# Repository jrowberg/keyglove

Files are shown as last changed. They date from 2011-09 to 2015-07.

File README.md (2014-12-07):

What is Keyglove?
=================

The [Keyglove](http://keyglove.net) is an [Arduino](http://arduino.cc)-powered glove that uses touch combinations to generate keyboard and mouse control codes. Once learned, the glove can easily be used without looking, making it perfect for embedded/wearable environments. The glove is thin and light, built to allow other activities (such as writing) without being in the way.

Keyglove Design
===============

Keyglove Prototype E

Because the glove design allows for multi-sensor combinations, the keyglove provides exponentially more possibilities than many other glove-based input devices (prototypes or commercial products). 34 strategically placed contact sensors and smart controller software make it possible to implement the entire English alphabet using simple one-to-one sensor contacts. When you include multi-sensor contacts, there are many hundreds of ergonomically usable combinations.

Development Status
==================

The Keyglove is still in the prototype stage with no fully working unit. For up-to-date development news, check out the [News](http://keyglove.net/news) page ([RSS here](http://keyglove.net/feed)) or follow the project on Twitter at [@keyglove](https://twitter.com/keyglove) or Facebook at https://fb.com/keyglove. You can also watch this repository for updates to all of the software, firmware, and hardware design resources.

For technical information, please visit the [How to Build](http://keyglove.net/build) page. It's not complete yet, but once the prototype is working the way I want it to, I will add better step-by-step instructions to the page.

You may also be interested in a [list of similar devices](http://keyglove.net/similar) I've come across on the internet, either to satisfy your curiosity, or out of a need for inspiration, or possibly to look for a product that might be more suited to your needs.

And, of course, you can always [contact me](http://keyglove.net/contact) with any questions, comments, ideas, etc.

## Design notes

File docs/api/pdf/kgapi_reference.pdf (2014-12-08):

# Keyglove API Reference Guide

2014-12-07

### keyglove.net github.com/jrowberg/keyglove

## This API Reference Guide describes the complete packet structure of all currently defined commands, responses, and events that are part of the Keyglove API binary

protocol.

This protocol is still under active development and has not been officially locked to a specific structure and definition. This means that the class/ID values as well as the parameter names, types, and order for any API method MAY CHANGE AT ANY TIME. Please make very sure that you are always working with the latest

available code and reference material.

# 1 Protocol class (ID = 0)

Protocol events occur when you try to use the protocol in an invalid way, or when you unintentionally send an incomplete command, invalid data, bad parameters, etc. They alert you to the fact that something has gone wrong.

There are no commands within this class; it only has events.

## 1.1 Events

### 1.1.1 protocol_error [ 80 02 00 01 ... ]

This event occurs when a problem exists with a command you have sent.

## INCOMING EVENT PACKET STRUCTURE

Byte | Type | Name | Description
0 | 0x80 | type | Event packet
1 | 0x02 | length | Fixedlength payload (2)
2 | 0x00 | class | Event class: "protocol"
3 | 0x01 | id | Event ID: "error"
4 5 | uint16_t | code | Error code describing what went wrong with the protocol communication Enum: protocol_error_code

1.1.1.1 Example Usage (Python)

# create callback for event

def my_kg_evt_protocol_error(sender, args): print("kg_evt_protocol_error: { code: %04X }" % (args['code']))

# assign callback function to appropriate KGLib event handler collection kglib.kg_evt_protocol_error += my_kg_evt_protocol_error

## 1.2 Enumerations

### 1.2.1 protocol_error_code

Describes the nature of a protocol error that has occurred.

Value | Name | Description
1 | invalid_command | Command class or ID is unknown
2 | packet_timeout | Command packet not completed in time
3 | bad_length | Length value not supported, 250 bytes or less
4 | parameter_length | Length of supplied parameters does not match with command definition
5 | parameter_range | Value of supplied parameter(s) outside of valid range
6 | not_implemented | Command known but not implemented in this firmware configuration

# 2 System class (ID = 1)

System commands and events relate to the core device, describing things like system boot and uptime, and verifying proper communication or resetting to an initial state.

## 2.1 Commands

### 2.1.1 system_ping [ C0 00 01 01 ]

Test communication with Keyglove device and get current uptime.

## OUTGOING COMMAND PACKET STRUCTURE

Byte | Type | Name | Description
0 | 0xC0 | type | Command packet
1 | 0x00 | length | No payload
2 | 0x01 | class | Command class: "system"
3 | 0x01 | id | Command ID: "ping"

## INCOMING RESPONSE PACKET STRUCTURE

Byte | Type | Name | Description
0 | 0xC0 | type | Response packet
1 | 0x04 | length | Fixedlength payload (4)
2 | 0x01 | class | Command class: "system"
3 | 0x01 | id | Command ID: "ping"
4 7 | uint32_t | uptime | Number of seconds since last boot/reset

2.1.1.1 Example Usage (Python)

# generate command packet only

packet = kglib.kg_cmd_system_ping()

# generate and send command

kglib.send_command(rxtx_obj, kglib.kg_cmd_system_ping())

# send command and wait for captured response

response = kglib.send_and_return(rxtx_obj, kglib.kg_cmd_system_ping(), timeout) print("kg_rsp_system_ping: { uptime: %08X }" % (response['payload']['uptime']))

# create separate callback for response

def my_kg_rsp_system_ping(sender, args):
print("kg_rsp_system_ping: { uptime: %08X }" % (args['uptime']))

# assign separate callback function to appropriate KGLib response handler collection kglib.kg_rsp_system_ping += my_kg_rsp_system_ping

### 2.1.2 system_reset [ C0 01 01 02 ... ]

Reset Keyglove device.

## OUTGOING COMMAND PACKET STRUCTURE

Byte | Type | Name | Description
0 | 0xC0 | type | Command packet
1 | 0x01 | length | Fixedlength payload (1)
2 | 0x01 | class | Command class: "system"
3 | 0x02 | id | Command ID: "reset"
4 | uint8_t | mode | Type of reset to perform Enum: system_reset_mode

## INCOMING RESPONSE PACKET STRUCTURE

Byte | Type | Name | Description
0 | 0xC0 | type | Response packet
1 | 0x02 | length | Fixedlength payload (2)
2 | 0x01 | class | Command class: "system"
3 | 0x02 | id | Command ID: "reset"
4 5 | uint16_t | result | Result code from 'reset' command

2.1.2.1 Example Usage (Python)

# generate command packet only

packet = kglib.kg_cmd_system_reset(mode)

# generate and send command

kglib.send_command(rxtx_obj, kglib.kg_cmd_system_reset(mode))

# send command and wait for captured response

response = kglib.send_and_return(rxtx_obj, kglib.kg_cmd_system_reset(mode), timeout) print("kg_rsp_system_reset: { result: %04X }" % (response['payload']['result']))

# create separate callback for response

def my_kg_rsp_system_reset(sender, args):
print("kg_rsp_system_reset: { result: %04X }" % (args['result']))

# assign separate callback function to appropriate KGLib response handler collection kglib.kg_rsp_system_reset += my_kg_rsp_system_reset

### 2.1.3 system_get_info [ C0 00 01 03 ]

Get firmware build info.

## OUTGOING COMMAND PACKET STRUCTURE

Byte | Type | Name | Description
0 | 0xC0 | type | Command packet
1 | 0x00 | length | No payload
2 | 0x01 | class | Command class: "system"
3 | 0x03 | id | Command ID: "get_info"

## INCOMING RESPONSE PACKET STRUCTURE

Byte | Type | Name | Description

0 | 0xC0 | type | Response packet
1 | 0x0C | length | Fixedlength payload (12)
2 | 0x01 | class | Command class: "system"
3 | 0x03 | id | Command ID: "get_info"
4 5 | uint16_t | major | Firmware major version number
6 7 | uint16_t | minor | Firmware minor version number
8 9 | uint16_t | patch | Firmware patch version number
10 11 | uint16_t | protocol | API protocol version number
12 15 | uint32_t | timestamp | Build timestamp

2.1.3.1 Example Usage (Python)

# generate command packet only

packet = kglib.kg_cmd_system_get_info()

# generate and send command

kglib.send_command(rxtx_obj, kglib.kg_cmd_system_get_info())

# send command and wait for captured response

response = kglib.send_and_return(rxtx_obj, kglib.kg_cmd_system_get_info(), timeout) print("kg_rsp_system_get_info: { major: %04X, minor: %04X, patch: %04X, protocol: %04X," \ " timestamp: %08X }" % (response['payload']['major'],' \
' response['payload']['minor'], response['payload']['patch'], \ response['payload']['protocol'], response['payload']['timestamp']))

# create separate callback for response

def my_kg_rsp_system_get_info(sender, args):
print("kg_rsp_system_get_info: { major: %04X, minor: %04X, patch: %04X, protocol:" \ " %04X, timestamp: %08X }" % (args['major'], args['minor'], args['patch'],' \ ' args['protocol'], args['timestamp']))

# assign separate callback function to appropriate KGLib response handler collection kglib.kg_rsp_system_get_info += my_kg_rsp_system_get_info

### 2.1.4 system_get_capabilities [ C0 01 01 04 ... ]

Get capabilities designed into this unit.

## OUTGOING COMMAND PACKET STRUCTURE

Byte | Type | Name | Description
0 | 0xC0 | type | Command packet
1 | 0x01 | length | Fixedlength payload (1)
2 | 0x01 | class | Command class: "system"
3 | 0x04 | id | Command ID: "get_capabilities"
4 | uint8_t | category | Category of capabilities to report (0xFF for all)

## INCOMING RESPONSE PACKET STRUCTURE

Byte | Type | Name | Description
0 | 0xC0 | type | Response packet

1 | 0x02 | length | Fixedlength payload (2)
2 | 0x01 | class | Command class: "system"
3 | 0x04 | id | Command ID: "get_capabilities"
4 5 | uint16_t | count | Number of capability reports to expect

2.1.4.1 Example Usage (Python)

# generate command packet only

packet = kglib.kg_cmd_system_get_capabilities(category)

# generate and send command

kglib.send_command(rxtx_obj, kglib.kg_cmd_system_get_capabilities(category))

# send command and wait for captured response

response = kglib.send_and_return(rxtx_obj, kglib.kg_cmd_system_get_capabilities(category), \ timeout)
print("kg_rsp_system_get_capabilities: { count: %04X }" % (response['payload']['count']))

# create separate callback for response

def my_kg_rsp_system_get_capabilities(sender, args): print("kg_rsp_system_get_capabilities: { count: %04X }" % (args['count']))

# assign separate callback function to appropriate KGLib response handler collection kglib.kg_rsp_system_get_capabilities += my_kg_rsp_system_get_capabilities

### 2.1.5 system_get_memory [ C0 00 01 05 ]

Get system memory usage.

## OUTGOING COMMAND PACKET STRUCTURE

Byte | Type | Name | Description
0 | 0xC0 | type | Command packet
1 | 0x00 | length | No payload
2 | 0x01 | class | Command class: "system"
3 | 0x05 | id | Command ID: "get_memory"

## INCOMING RESPONSE PACKET STRUCTURE

Byte | Type | Name | Description
0 | 0xC0 | type | Response packet
1 | 0x08 | length | Fixedlength payload (8)
2 | 0x01 | class | Command class: "system"
3 | 0x05 | id | Command ID: "get_memory"
4 7 | uint32_t | free_ram | Free bytes of RAM
8 11 | uint32_t | total_ram | Total bytes of RAM

2.1.5.1 Example Usage (Python)

# generate command packet only

packet = kglib.kg_cmd_system_get_memory()

# generate and send command

kglib.send_command(rxtx_obj, kglib.kg_cmd_system_get_memory())

# send command and wait for captured response

response = kglib.send_and_return(rxtx_obj, kglib.kg_cmd_system_get_memory(), timeout) print("kg_rsp_system_get_memory: { free_ram: %08X, total_ram: %08X }" % \ (response['payload']['free_ram'], response['payload']['total_ram']))

# create separate callback for response

def my_kg_rsp_system_get_memory(sender, args):
print("kg_rsp_system_get_memory: { free_ram: %08X, total_ram: %08X }" % \ (args['free_ram'], args['total_ram']))

# assign separate callback function to appropriate KGLib response handler collection kglib.kg_rsp_system_get_memory += my_kg_rsp_system_get_memory

### 2.1.6 system_get_battery_status [ C0 00 01 06 ]

Get battery status (presence, charge status, charge level)

## OUTGOING COMMAND PACKET STRUCTURE

Byte | Type | Name | Description
0 | 0xC0 | type | Command packet
1 | 0x00 | length | No payload
2 | 0x01 | class | Command class: "system"
3 | 0x06 | id | Command ID: "get_battery_status"

## INCOMING RESPONSE PACKET STRUCTURE

Byte | Type | Name | Description
0 | 0xC0 | type | Response packet
1 | 0x02 | length | Fixedlength payload (2)
2 | 0x01 | class | Command class: "system"
3 | 0x06 | id | Command ID: "get_battery_status"
4 | uint8_t | status | Battery status
5 | uint8_t | level | Charge level (0-100)

2.1.6.1 Example Usage (Python)

# generate command packet only

packet = kglib.kg_cmd_system_get_battery_status()

# generate and send command

kglib.send_command(rxtx_obj, kglib.kg_cmd_system_get_battery_status())

# send command and wait for captured response

response = kglib.send_and_return(rxtx_obj, kglib.kg_cmd_system_get_battery_status(), \ timeout)
print("kg_rsp_system_get_battery_status: { status: %02X, level: %02X }" % \ (response['payload']['status'], response['payload']['level']))

# create separate callback for response

def my_kg_rsp_system_get_battery_status(sender, args): print("kg_rsp_system_get_battery_status: { status: %02X, level: %02X }" % \ (args['status'], args['level']))

# assign separate callback function to appropriate KGLib response handler collection kglib.kg_rsp_system_get_battery_status += my_kg_rsp_system_get_battery_status

### 2.1.7 system_set_timer [ C0 04 01 07 ... ]

Set a timer interval to trigger future behavior.

## OUTGOING COMMAND PACKET STRUCTURE

Byte | Type | Name | Description
0 | 0xC0 | type | Command packet
1 | 0x04 | length | Fixedlength payload (4)
2 | 0x01 | class | Command class: "system"
3 | 0x07 | id | Command ID: "set_timer"
4 | uint8_t | handle | Timer handle (0-7)
5 6 | uint16_t | interval | Interval (10ms units)
7 | uint8_t | oneshot | Repeating (0) or oneshot (1)

## INCOMING RESPONSE PACKET STRUCTURE

Byte | Type | Name | Description
0 | 0xC0 | type | Response packet
1 | 0x02 | length | Fixedlength payload (2)
2 | 0x01 | class | Command class: "system"
3 | 0x07 | id | Command ID: "set_timer"
4 5 | uint16_t | result | Result code from 'set_timer' command

2.1.7.1 Example Usage (Python)

# generate command packet only

packet = kglib.kg_cmd_system_set_timer(handle, interval, oneshot)

# generate and send command

kglib.send_command(rxtx_obj, kglib.kg_cmd_system_set_timer(handle, interval, oneshot))

# send command and wait for captured response

response = kglib.send_and_return(rxtx_obj, kglib.kg_cmd_system_set_timer(handle, interval, \ oneshot), timeout)
print("kg_rsp_system_set_timer: { result: %04X }" % (response['payload']['result']))

# create separate callback for response

def my_kg_rsp_system_set_timer(sender, args):
print("kg_rsp_system_set_timer: { result: %04X }" % (args['result']))

# assign separate callback function to appropriate KGLib response handler collection kglib.kg_rsp_system_set_timer += my_kg_rsp_system_set_timer

## 2.2 Events

### 2.2.1 system_boot [ 80 0C 01 01 ... ]

Indicates that Keyglove has started the boot process.

## INCOMING EVENT PACKET STRUCTURE

Byte | Type | Name | Description
0 | 0x80 | type | Event packet
1 | 0x0C | length | Fixedlength payload (12)
2 | 0x01 | class | Event class: "system"
3 | 0x01 | id | Event ID: "boot"
4 5 | uint16_t | major | Firmware major version number
6 7 | uint16_t | minor | Firmware minor version number
8 9 | uint16_t | patch | Firmware patch version number
10 11 | uint16_t | protocol | API protocol version number
12 15 | uint32_t | timestamp | Build timestamp

2.2.1.1 Example Usage (Python)

# create callback for event

def my_kg_evt_system_boot(sender, args):
print("kg_evt_system_boot: { major: %04X, minor: %04X, patch: %04X, protocol: %04X," \ " timestamp: %08X }" % (args['major'], args['minor'], args['patch'],' \ ' args['protocol'], args['timestamp']))

# assign callback function to appropriate KGLib event handler collection kglib.kg_evt_system_boot += my_kg_evt_system_boot

### 2.2.2 system_ready [ 80 00 01 02 ]

Indicates that Keyglove has completed the boot process and is ready for use.

## INCOMING EVENT PACKET STRUCTURE

Byte | Type | Name | Description
0 | 0x80 | type | Event packet
1 | 0x00 | length | No payload
2 | 0x01 | class | Event class: "system"
3 | 0x02 | id | Event ID: "ready"

2.2.2.1 Example Usage (Python)

# create callback for event

def my_kg_evt_system_ready(sender, args):
print("kg_evt_system_ready: { }")

# assign callback function to appropriate KGLib event handler collection kglib.kg_evt_system_ready += my_kg_evt_system_ready

### 2.2.3 system_error [ 80 02 01 03 ... ]

Indicates that Keyglove has encountered an error (RAM, hardware, etc.) that will result in unintended behavior.

## INCOMING EVENT PACKET STRUCTURE

Byte | Type | Name | Description
0 | 0x80 | type | Event packet
1 | 0x02 | length | Fixedlength payload (2)
2 | 0x01 | class | Event class: "system"
3 | 0x03 | id | Event ID: "error"
4 5 | uint16_t | code | Error code describing what went wrong with the system Enum: system_error_code

2.2.3.1 Example Usage (Python)

# create callback for event

def my_kg_evt_system_error(sender, args):
print("kg_evt_system_error: { code: %04X }" % (args['code']))

# assign callback function to appropriate KGLib event handler collection kglib.kg_evt_system_error += my_kg_evt_system_error

### 2.2.4 system_capability [ 80 03+ 01 04 ... ]

Provides a record describing specific capabilities designed into this unit.

## INCOMING EVENT PACKET STRUCTURE

Byte | Type | Name | Description
0 | 0x80 | type | Event packet
1 | 0x03+ | length | Variablelength payload (3+)
2 | 0x01 | class | Event class: "system"
3 | 0x04 | id | Event ID: "capability"
4 5 | uint16_t | category | Category that this capability report is included in
6 | uint8_t[] | record | Capability record(s) in typelengthvalue format

2.2.4.1 Example Usage (Python)

# create callback for event

def my_kg_evt_system_capability(sender, args):
print("kg_evt_system_capability: { category: %04X, record: %s }" % (args['category'], \ ' '.join(['%02X' % b for b in args['record']])))

# assign callback function to appropriate KGLib event handler collection kglib.kg_evt_system_capability += my_kg_evt_system_capability

### 2.2.5 system_battery_status [ 80 02 01 05 ... ]

Indicates that battery status has changed

## INCOMING EVENT PACKET STRUCTURE

Byte | Type | Name | Description
0 | 0x80 | type | Event packet

1 | 0x02 | length | Fixedlength payload (2)
2 | 0x01 | class | Event class: "system"
3 | 0x05 | id | Event ID: "battery_status"
4 | uint8_t | status | Battery status
5 | uint8_t | level | Charge level (0-100)

2.2.5.1 Example Usage (Python)

# create callback for event

def my_kg_evt_system_battery_status(sender, args):
print("kg_evt_system_battery_status: { status: %02X, level: %02X }" % (args['status'], \ args['level']))

# assign callback function to appropriate KGLib event handler collection kglib.kg_evt_system_battery_status += my_kg_evt_system_battery_status

### 2.2.6 system_timer_tick [ 80 06 01 06 ... ]

Indicates that a previously scheduled software timer has elapsed.

## INCOMING EVENT PACKET STRUCTURE

Byte | Type | Name | Description
0 | 0x80 | type | Event packet
1 | 0x06 | length | Fixedlength payload (6)
2 | 0x01 | class | Event class: "system"
3 | 0x06 | id | Event ID: "timer_tick"
4 | uint8_t | handle | Timer handle which triggered this event
5 8 | uint32_t | seconds | Seconds elapsed since boot
9 | uint8_t | subticks | 10ms subticks above whole second

2.2.6.1 Example Usage (Python)

# create callback for event

def my_kg_evt_system_timer_tick(sender, args):
print("kg_evt_system_timer_tick: { handle: %02X, seconds: %08X, subticks: %02X }" % \ (args['handle'], args['seconds'], args['subticks']))

# assign callback function to appropriate KGLib event handler collection kglib.kg_evt_system_timer_tick += my_kg_evt_system_timer_tick

## 2.3 Enumerations

### 2.3.1 system_error_code

Describes the nature of a system error that has occurred.

Value | Name | Description
1 | out_of_memory | Could not allocate required memory

### 2.3.1 system_reset_mode

Describes the type of reset to perform.

Value | Name | Description
1 | normal | Reset Keyglove hardware and all peripherals (Bluetooth, sensors, etc.)
2 | kgonly | Reset Keyglove hardware only, no peripherals

# 3 Touch class (ID = 2)

Touch commands and events control and report the behavior of the touch detection interface.

## 3.1 Commands

### 3.1.1 touch_get_mode [ C0 00 02 01 ]

Get the current touch mode.

## OUTGOING COMMAND PACKET STRUCTURE

Byte | Type | Name | Description
0 | 0xC0 | type | Command packet
1 | 0x00 | length | No payload
2 | 0x02 | class | Command class: "touch"
3 | 0x01 | id | Command ID: "get_mode"

## INCOMING RESPONSE PACKET STRUCTURE

Byte | Type | Name | Description
0 | 0xC0 | type | Response packet
1 | 0x01 | length | Fixedlength payload (1)
2 | 0x02 | class | Command class: "touch"
3 | 0x01 | id | Command ID: "get_mode"
4 | uint8_t | mode | Current touch mode setting

3.1.1.1 Example Usage (Python)

# generate command packet only

packet = kglib.kg_cmd_touch_get_mode()

# generate and send command

kglib.send_command(rxtx_obj, kglib.kg_cmd_touch_get_mode())

# send command and wait for captured response

response = kglib.send_and_return(rxtx_obj, kglib.kg_cmd_touch_get_mode(), timeout) print("kg_rsp_touch_get_mode: { mode: %02X }" % (response['payload']['mode']))

# create separate callback for response

def my_kg_rsp_touch_get_mode(sender, args):
print("kg_rsp_touch_get_mode: { mode: %02X }" % (args['mode']))

# assign separate callback function to appropriate KGLib response handler collection kglib.kg_rsp_touch_get_mode += my_kg_rsp_touch_get_mode

### 3.1.2 touch_set_mode [ C0 01 02 02 ... ]

Set a new touch mode.

## OUTGOING COMMAND PACKET STRUCTURE

Byte | Type | Name | Description

0 | 0xC0 | type | Command packet
1 | 0x01 | length | Fixedlength payload (1)
2 | 0x02 | class | Command class: "touch"
3 | 0x02 | id | Command ID: "set_mode"
4 | uint8_t | mode | New touch mode to set

## INCOMING RESPONSE PACKET STRUCTURE

Byte | Type | Name | Description
0 | 0xC0 | type | Response packet
1 | 0x02 | length | Fixedlength payload (2)
2 | 0x02 | class | Command class: "touch"
3 | 0x02 | id | Command ID: "set_mode"
4 5 | uint16_t | result | Result code from 'set_mode' command

3.1.2.1 Example Usage (Python)

# generate command packet only

packet = kglib.kg_cmd_touch_set_mode(mode)

# generate and send command

kglib.send_command(rxtx_obj, kglib.kg_cmd_touch_set_mode(mode))

# send command and wait for captured response

response = kglib.send_and_return(rxtx_obj, kglib.kg_cmd_touch_set_mode(mode), timeout) print("kg_rsp_touch_set_mode: { result: %04X }" % (response['payload']['result']))

# create separate callback for response

def my_kg_rsp_touch_set_mode(sender, args):
print("kg_rsp_touch_set_mode: { result: %04X }" % (args['result']))

# assign separate callback function to appropriate KGLib response handler collection kglib.kg_rsp_touch_set_mode += my_kg_rsp_touch_set_mode

## 3.2 Events

### 3.2.1 touch_mode [ 80 01 02 01 ... ]

Indicates that the touch mode has changed.

## INCOMING EVENT PACKET STRUCTURE

Byte | Type | Name | Description
0 | 0x80 | type | Event packet
1 | 0x01 | length | Fixedlength payload (1)
2 | 0x02 | class | Event class: "touch"
3 | 0x01 | id | Event ID: "mode"
4 | uint8_t | mode | New touch mode

3.2.1.1 Example Usage (Python)

# create callback for event

def my_kg_evt_touch_mode(sender, args):
print("kg_evt_touch_mode: { mode: %02X }" % (args['mode']))

# assign callback function to appropriate KGLib event handler collection kglib.kg_evt_touch_mode += my_kg_evt_touch_mode

### 3.2.2 touch_status [ 80 01+ 02 02 ... ]

Indicates that the touch sensor status has changed.

## INCOMING EVENT PACKET STRUCTURE

Byte | Type | Name | Description
0 | 0x80 | type | Event packet
1 | 0x01+ | length | Variablelength payload (1+)
2 | 0x02 | class | Event class: "touch"
3 | 0x02 | id | Event ID: "status"
4 | uint8_t[] | status | New touch status

3.2.2.1 Example Usage (Python)

# create callback for event

def my_kg_evt_touch_status(sender, args):
print("kg_evt_touch_status: { status: %s }" % (' '.join(['%02X' % b for b in \ args['status']])))

# assign callback function to appropriate KGLib event handler collection kglib.kg_evt_touch_status += my_kg_evt_touch_status

# 4 Feedback class (ID = 3)

Feedback commands and events control and report on the various types of feedback subsystems, such as a simple LED or more complex devices such as RGB LEDs or piezo buzzers.

## 4.1 Commands

### 4.1.1 feedback_get_blink_mode [ C0 00 03 01 ]

Get current blink feedback mode.

## OUTGOING COMMAND PACKET STRUCTURE

Byte | Type | Name | Description
0 | 0xC0 | type | Command packet
1 | 0x00 | length | No payload
2 | 0x03 | class | Command class: "feedback"
3 | 0x01 | id | Command ID: "get_blink_mode"

## INCOMING RESPONSE PACKET STRUCTURE

Byte | Type | Name | Description
0 | 0xC0 | type | Response packet
1 | 0x01 | length | Fixedlength payload (1)
2 | 0x03 | class | Command class: "feedback"
3 | 0x01 | id | Command ID: "get_blink_mode"
4 | uint8_t | mode | Current blink feedback mode

4.1.1.1 Example Usage (Python)

# generate command packet only

packet = kglib.kg_cmd_feedback_get_blink_mode()

# generate and send command

kglib.send_command(rxtx_obj, kglib.kg_cmd_feedback_get_blink_mode())

# send command and wait for captured response

response = kglib.send_and_return(rxtx_obj, kglib.kg_cmd_feedback_get_blink_mode(), timeout) print("kg_rsp_feedback_get_blink_mode: { mode: %02X }" % (response['payload']['mode']))

# create separate callback for response

def my_kg_rsp_feedback_get_blink_mode(sender, args): print("kg_rsp_feedback_get_blink_mode: { mode: %02X }" % (args['mode']))

# assign separate callback function to appropriate KGLib response handler collection kglib.kg_rsp_feedback_get_blink_mode += my_kg_rsp_feedback_get_blink_mode

### 4.1.2 feedback_set_blink_mode [ C0 01 03 02 ... ]

Set new blink feedback mode.

## OUTGOING COMMAND PACKET STRUCTURE

Byte | Type | Name | Description
0 | 0xC0 | type | Command packet
1 | 0x01 | length | Fixedlength payload (1)
2 | 0x03 | class | Command class: "feedback"
3 | 0x02 | id | Command ID: "set_blink_mode"
4 | uint8_t | mode | New blink feedback mode to set

## INCOMING RESPONSE PACKET STRUCTURE

Byte | Type | Name | Description
0 | 0xC0 | type | Response packet
1 | 0x02 | length | Fixedlength payload (2)
2 | 0x03 | class | Command class: "feedback"
3 | 0x02 | id | Command ID: "set_blink_mode"
4 5 | uint16_t | result | Result code from command

4.1.2.1 Example Usage (Python)

# generate command packet only

packet = kglib.kg_cmd_feedback_set_blink_mode(mode)

# generate and send command

kglib.send_command(rxtx_obj, kglib.kg_cmd_feedback_set_blink_mode(mode))

# send command and wait for captured response

response = kglib.send_and_return(rxtx_obj, kglib.kg_cmd_feedback_set_blink_mode(mode), \ timeout)
print("kg_rsp_feedback_set_blink_mode: { result: %04X }" % (response['payload']['result']))

# create separate callback for response

def my_kg_rsp_feedback_set_blink_mode(sender, args): print("kg_rsp_feedback_set_blink_mode: { result: %04X }" % (args['result']))

# assign separate callback function to appropriate KGLib response handler collection kglib.kg_rsp_feedback_set_blink_mode += my_kg_rsp_feedback_set_blink_mode

### 4.1.3 feedback_get_piezo_mode [ C0 01 03 03 ... ]

Get current feedback mode for a piezo buzzer.

## OUTGOING COMMAND PACKET STRUCTURE

Byte | Type | Name | Description
0 | 0xC0 | type | Command packet
1 | 0x01 | length | Fixedlength payload (1)
2 | 0x03 | class | Command class: "feedback"
3 | 0x03 | id | Command ID: "get_piezo_mode"
4 | uint8_t | index | Index of piezo device for which to get the current mode

## INCOMING RESPONSE PACKET STRUCTURE

Byte | Type | Name | Description
0 | 0xC0 | type | Response packet
1 | 0x04 | length | Fixedlength payload (4)
2 | 0x03 | class | Command class: "feedback"
3 | 0x03 | id | Command ID: "get_piezo_mode"
4 | uint8_t | mode | Current feedback mode for specified piezo device
5 | uint8_t | duration | Duration to maintain tone
6 7 | uint16_t | frequency | Frequency of tone to generate

4.1.3.1 Example Usage (Python)

# generate command packet only

packet = kglib.kg_cmd_feedback_get_piezo_mode(index)

# generate and send command

kglib.send_command(rxtx_obj, kglib.kg_cmd_feedback_get_piezo_mode(index))

# send command and wait for captured response

response = kglib.send_and_return(rxtx_obj, kglib.kg_cmd_feedback_get_piezo_mode(index), \ timeout)
print("kg_rsp_feedback_get_piezo_mode: { mode: %02X, duration: %02X, frequency: %04X }" % \ (response['payload']['mode'], response['payload']['duration'], \ response['payload']['frequency']))

# create separate callback for response

def my_kg_rsp_feedback_get_piezo_mode(sender, args): print("kg_rsp_feedback_get_piezo_mode: { mode: %02X, duration: %02X, frequency: %04X" \ " }" % (args['mode'], args['duration'], args['frequency']))

# assign separate callback function to appropriate KGLib response handler collection kglib.kg_rsp_feedback_get_piezo_mode += my_kg_rsp_feedback_get_piezo_mode

### 4.1.4 feedback_set_piezo_mode [ C0 05 03 04 ... ]

Set a new piezo feedback mode for a piezo buzzer.

## OUTGOING COMMAND PACKET STRUCTURE

Byte | Type | Name | Description
0 | 0xC0 | type | Command packet
1 | 0x05 | length | Fixedlength payload (5)
2 | 0x03 | class | Command class: "feedback"
3 | 0x04 | id | Command ID: "set_piezo_mode"
4 | uint8_t | index | Index of piezo device for which to set a new mode
5 | uint8_t | mode | New feedback mode to set for specified piezo device
6 | uint8_t | duration | Duration to maintain tone
7 8 | uint16_t | frequency | Frequency of tone to generate

## INCOMING RESPONSE PACKET STRUCTURE

Byte | Type | Name | Description
0 | 0xC0 | type | Response packet
1 | 0x02 | length | Fixedlength payload (2)
2 | 0x03 | class | Command class: "feedback"
3 | 0x04 | id | Command ID: "set_piezo_mode"
4 5 | uint16_t | result | Result code from command

4.1.4.1 Example Usage (Python)

# generate command packet only

packet = kglib.kg_cmd_feedback_set_piezo_mode(index, mode, duration, frequency)

# generate and send command

kglib.send_command(rxtx_obj, kglib.kg_cmd_feedback_set_piezo_mode(index, mode, duration, \ frequency))

# send command and wait for captured response

response = kglib.send_and_return(rxtx_obj, kglib.kg_cmd_feedback_set_piezo_mode(index, \ mode, duration, frequency), timeout) print("kg_rsp_feedback_set_piezo_mode: { result: %04X }" % (response['payload']['result']))

# create separate callback for response

def my_kg_rsp_feedback_set_piezo_mode(sender, args): print("kg_rsp_feedback_set_piezo_mode: { result: %04X }" % (args['result']))

# assign separate callback function to appropriate KGLib response handler collection kglib.kg_rsp_feedback_set_piezo_mode += my_kg_rsp_feedback_set_piezo_mode

### 4.1.5 feedback_get_vibrate_mode [ C0 01 03 05 ... ]

Get current feedback mode for a vibration motor.

## OUTGOING COMMAND PACKET STRUCTURE

Byte | Type | Name | Description
0 | 0xC0 | type | Command packet
1 | 0x01 | length | Fixedlength payload (1)
2 | 0x03 | class | Command class: "feedback"
3 | 0x05 | id | Command ID: "get_vibrate_mode"
4 | uint8_t | index | Index of vibration device for which to get the current mode

## INCOMING RESPONSE PACKET STRUCTURE

Byte | Type | Name | Description
0 | 0xC0 | type | Response packet
1 | 0x02 | length | Fixedlength payload (2)
2 | 0x03 | class | Command class: "feedback"
3 | 0x05 | id | Command ID: "get_vibrate_mode"
4 | uint8_t | mode | Current feedback mode for specified vibration device
5 | uint8_t | duration | Duration to maintain vibration

4.1.5.1 Example Usage (Python)

# generate command packet only

packet = kglib.kg_cmd_feedback_get_vibrate_mode(index)

# generate and send command

kglib.send_command(rxtx_obj, kglib.kg_cmd_feedback_get_vibrate_mode(index))

# send command and wait for captured response

response = kglib.send_and_return(rxtx_obj, kglib.kg_cmd_feedback_get_vibrate_mode(index), \ timeout)
print("kg_rsp_feedback_get_vibrate_mode: { mode: %02X, duration: %02X }" % \ (response['payload']['mode'], response['payload']['duration']))

# create separate callback for response

def my_kg_rsp_feedback_get_vibrate_mode(sender, args): print("kg_rsp_feedback_get_vibrate_mode: { mode: %02X, duration: %02X }" % \ (args['mode'], args['duration']))

# assign separate callback function to appropriate KGLib response handler collection kglib.kg_rsp_feedback_get_vibrate_mode += my_kg_rsp_feedback_get_vibrate_mode

### 4.1.6 feedback_set_vibrate_mode [ C0 03 03 06 ... ]

Set a new vibration motor feedback mode.

## OUTGOING COMMAND PACKET STRUCTURE

Byte | Type | Name | Description
0 | 0xC0 | type | Command packet
1 | 0x03 | length | Fixedlength payload (3)
2 | 0x03 | class | Command class: "feedback"
3 | 0x06 | id | Command ID: "set_vibrate_mode"
4 | uint8_t | index | Index of vibration device for which to set a new mode
5 | uint8_t | mode | New feedback mode to set for specified vibration device
6 | uint8_t | duration | Duration to maintain vibration

## INCOMING RESPONSE PACKET STRUCTURE

Byte | Type | Name | Description
0 | 0xC0 | type | Response packet
1 | 0x02 | length | Fixedlength payload (2)
2 | 0x03 | class | Command class: "feedback"
3 | 0x06 | id | Command ID: "set_vibrate_mode"
4 5 | uint16_t | result | Result code from command

4.1.6.1 Example Usage (Python)

# generate command packet only

packet = kglib.kg_cmd_feedback_set_vibrate_mode(index, mode, duration)

# generate and send command

kglib.send_command(rxtx_obj, kglib.kg_cmd_feedback_set_vibrate_mode(index, mode, duration))

# send command and wait for captured response

response = kglib.send_and_return(rxtx_obj, kglib.kg_cmd_feedback_set_vibrate_mode(index, \ mode, duration), timeout)
print("kg_rsp_feedback_set_vibrate_mode: { result: %04X }" % \ (response['payload']['result']))

# create separate callback for response

def my_kg_rsp_feedback_set_vibrate_mode(sender, args): print("kg_rsp_feedback_set_vibrate_mode: { result: %04X }" % (args['result']))

# assign separate callback function to appropriate KGLib response handler collection kglib.kg_rsp_feedback_set_vibrate_mode += my_kg_rsp_feedback_set_vibrate_mode

### 4.1.7 feedback_get_rgb_mode [ C0 01 03 07 ... ]

Get current feedback mode for an RGB LED.

## OUTGOING COMMAND PACKET STRUCTURE

Byte | Type | Name | Description
0 | 0xC0 | type | Command packet
1 | 0x01 | length | Fixedlength payload (1)
2 | 0x03 | class | Command class: "feedback"
3 | 0x07 | id | Command ID: "get_rgb_mode"
4 | uint8_t | index | Index of RGB device for which to get the current mode

## INCOMING RESPONSE PACKET STRUCTURE

Byte | Type | Name | Description
0 | 0xC0 | type | Response packet
1 | 0x03 | length | Fixedlength payload (3)
2 | 0x03 | class | Command class: "feedback"
3 | 0x07 | id | Command ID: "get_rgb_mode"
4 | uint8_t | mode_red | Current feedback mode for specified RGB device red LED
5 | uint8_t | mode_green | Current feedback mode for specified RGB device green LED
6 | uint8_t | mode_blue | Current feedback mode for specified RGB device blue LED

4.1.7.1 Example Usage (Python)

# generate command packet only

packet = kglib.kg_cmd_feedback_get_rgb_mode(index)

# generate and send command

kglib.send_command(rxtx_obj, kglib.kg_cmd_feedback_get_rgb_mode(index))

# send command and wait for captured response

response = kglib.send_and_return(rxtx_obj, kglib.kg_cmd_feedback_get_rgb_mode(index), \ timeout)

print("kg_rsp_feedback_get_rgb_mode: { mode_red: %02X, mode_green: %02X, mode_blue: %02X" \ " }" % (response['payload']['mode_red'], response['payload']['mode_green'], \ response['payload']['mode_blue']))

# create separate callback for response

def my_kg_rsp_feedback_get_rgb_mode(sender, args):
print("kg_rsp_feedback_get_rgb_mode: { mode_red: %02X, mode_green: %02X, mode_blue:" \ " %02X }" % (args['mode_red'], args['mode_green'], args['mode_blue']))

# assign separate callback function to appropriate KGLib response handler collection kglib.kg_rsp_feedback_get_rgb_mode += my_kg_rsp_feedback_get_rgb_mode

### 4.1.8 feedback_set_rgb_mode [ C0 04 03 08 ... ]

Set a new RGB LED feedback mode.

## OUTGOING COMMAND PACKET STRUCTURE

Byte | Type | Name | Description
0 | 0xC0 | type | Command packet
1 | 0x04 | length | Fixedlength payload (4)
2 | 0x03 | class | Command class: "feedback"
3 | 0x08 | id | Command ID: "set_rgb_mode"
4 | uint8_t | index | Index of RGB device for which to set a new mode
5 | uint8_t | mode_red | New feedback mode to set for specified RGB device red LED
6 | uint8_t | mode_green | New feedback mode to set for specified RGB device green LED
7 | uint8_t | mode_blue | New feedback mode to set for specified RGB device blue LED

## INCOMING RESPONSE PACKET STRUCTURE

Byte | Type | Name | Description
0 | 0xC0 | type | Response packet
1 | 0x02 | length | Fixedlength payload (2)
2 | 0x03 | class | Command class: "feedback"
3 | 0x08 | id | Command ID: "set_rgb_mode"
4 5 | uint16_t | result | Result code from command

4.1.8.1 Example Usage (Python)

# generate command packet only

packet = kglib.kg_cmd_feedback_set_rgb_mode(index, mode_red, mode_green, mode_blue)

# generate and send command

kglib.send_command(rxtx_obj, kglib.kg_cmd_feedback_set_rgb_mode(index, mode_red, \ mode_green, mode_blue))

# send command and wait for captured response

response = kglib.send_and_return(rxtx_obj, kglib.kg_cmd_feedback_set_rgb_mode(index, \ mode_red, mode_green, mode_blue), timeout) print("kg_rsp_feedback_set_rgb_mode: { result: %04X }" % (response['payload']['result']))

# create separate callback for response

def my_kg_rsp_feedback_set_rgb_mode(sender, args): print("kg_rsp_feedback_set_rgb_mode: { result: %04X }" % (args['result']))

# assign separate callback function to appropriate KGLib response handler collection kglib.kg_rsp_feedback_set_rgb_mode += my_kg_rsp_feedback_set_rgb_mode

## 4.2 Events

### 4.2.1 feedback_blink_mode [ 80 01 03 01 ... ]

Indicates that the blink feedback mode has changed.

## INCOMING EVENT PACKET STRUCTURE

Byte | Type | Name | Description
0 | 0x80 | type | Event packet
1 | 0x01 | length | Fixedlength payload (1)
2 | 0x03 | class | Event class: "feedback"
3 | 0x01 | id | Event ID: "blink_mode"
4 | uint8_t | mode | New blink feedback mode

4.2.1.1 Example Usage (Python)

# create callback for event

def my_kg_evt_feedback_blink_mode(sender, args): print("kg_evt_feedback_blink_mode: { mode: %02X }" % (args['mode']))

# assign callback function to appropriate KGLib event handler collection kglib.kg_evt_feedback_blink_mode += my_kg_evt_feedback_blink_mode

### 4.2.2 feedback_piezo_mode [ 80 05 03 02 ... ]

Indicates that a piezo buzzer feedback mode has changed.

## INCOMING EVENT PACKET STRUCTURE

Byte | Type | Name | Description
0 | 0x80 | type | Event packet
1 | 0x05 | length | Fixedlength payload (5)
2 | 0x03 | class | Event class: "feedback"
3 | 0x02 | id | Event ID: "piezo_mode"
4 | uint8_t | index | Piezo feedback device index
5 | uint8_t | mode | New piezo feedback mode for indicated piezo device
6 | uint8_t | duration | Duration to maintain tone
7 8 | uint16_t | frequency | Frequency of tone to generate

4.2.2.1 Example Usage (Python)

# create callback for event

def my_kg_evt_feedback_piezo_mode(sender, args):
print("kg_evt_feedback_piezo_mode: { index: %02X, mode: %02X, duration: %02X," \

" frequency: %04X }" % (args['index'], args['mode'], args['duration'],' \ ' args['frequency']))

# assign callback function to appropriate KGLib event handler collection kglib.kg_evt_feedback_piezo_mode += my_kg_evt_feedback_piezo_mode

### 4.2.3 feedback_vibrate_mode [ 80 03 03 03 ... ]

Indicates that a vibration feedback mode has changed.

## INCOMING EVENT PACKET STRUCTURE

Byte | Type | Name | Description
0 | 0x80 | type | Event packet
1 | 0x03 | length | Fixedlength payload (3)
2 | 0x03 | class | Event class: "feedback"
3 | 0x03 | id | Event ID: "vibrate_mode"
4 | uint8_t | index | Vibration feedback device index
5 | uint8_t | mode | New vibration feedback mode for indicated vibration device
6 | uint8_t | duration | Duration to maintain vibration

4.2.3.1 Example Usage (Python)

# create callback for event

def my_kg_evt_feedback_vibrate_mode(sender, args):
print("kg_evt_feedback_vibrate_mode: { index: %02X, mode: %02X, duration: %02X }" % \ (args['index'], args['mode'], args['duration']))

# assign callback function to appropriate KGLib event handler collection kglib.kg_evt_feedback_vibrate_mode += my_kg_evt_feedback_vibrate_mode

### 4.2.4 feedback_rgb_mode [ 80 04 03 04 ... ]

Indicates that an RGB LED feedback mode has changed.

## INCOMING EVENT PACKET STRUCTURE

Byte | Type | Name | Description
0 | 0x80 | type | Event packet
1 | 0x04 | length | Fixedlength payload (4)
2 | 0x03 | class | Event class: "feedback"
3 | 0x04 | id | Event ID: "rgb_mode"
4 | uint8_t | index | RGB feedback device index
5 | uint8_t | mode_red | New feedback mode for indicated RGB device red LED
6 | uint8_t | mode_green | New feedback mode for indicated RGB device green LED
7 | uint8_t | mode_blue | New feedback mode for indicated RGB device blue LED

4.2.4.1 Example Usage (Python)

# create callback for event

def my_kg_evt_feedback_rgb_mode(sender, args):

print("kg_evt_feedback_rgb_mode: { index: %02X, mode_red: %02X, mode_green: %02X," \ " mode_blue: %02X }" % (args['index'], args['mode_red'], args['mode_green'],' \ ' args['mode_blue']))

# assign callback function to appropriate KGLib event handler collection kglib.kg_evt_feedback_rgb_mode += my_kg_evt_feedback_rgb_mode

# 5 Motion class (ID = 4)

Motion commands and events allow the control and detection of various motion sensors in the design.

## 5.1 Commands

### 5.1.1 motion_get_mode [ C0 01 04 01 ... ]

Get current mode for specified motion sensor.

## OUTGOING COMMAND PACKET STRUCTURE

Byte | Type | Name | Description
0 | 0xC0 | type | Command packet
1 | 0x01 | length | Fixedlength payload (1)
2 | 0x04 | class | Command class: "motion"
3 | 0x01 | id | Command ID: "get_mode"
4 | uint8_t | index | Index of motion sensor for which to get the current mode

## INCOMING RESPONSE PACKET STRUCTURE

Byte | Type | Name | Description
0 | 0xC0 | type | Response packet
1 | 0x01 | length | Fixedlength payload (1)
2 | 0x04 | class | Command class: "motion"
3 | 0x01 | id | Command ID: "get_mode"
4 | uint8_t | mode | Current motion sensor mode

5.1.1.1 Example Usage (Python)

# generate command packet only

packet = kglib.kg_cmd_motion_get_mode(index)

# generate and send command

kglib.send_command(rxtx_obj, kglib.kg_cmd_motion_get_mode(index))

# send command and wait for captured response

response = kglib.send_and_return(rxtx_obj, kglib.kg_cmd_motion_get_mode(index), timeout) print("kg_rsp_motion_get_mode: { mode: %02X }" % (response['payload']['mode']))

# create separate callback for response

def my_kg_rsp_motion_get_mode(sender, args):
print("kg_rsp_motion_get_mode: { mode: %02X }" % (args['mode']))

# assign separate callback function to appropriate KGLib response handler collection kglib.kg_rsp_motion_get_mode += my_kg_rsp_motion_get_mode

### 5.1.2 motion_set_mode [ C0 02 04 02 ... ]

Set new mode for specified motion sensor.

## OUTGOING COMMAND PACKET STRUCTURE

Byte | Type | Name | Description
0 | 0xC0 | type | Command packet
1 | 0x02 | length | Fixedlength payload (2)
2 | 0x04 | class | Command class: "motion"
3 | 0x02 | id | Command ID: "set_mode"
4 | uint8_t | index | Index of motion sensor for which to get the current mode
5 | uint8_t | mode | New motion sensor mode to set

## INCOMING RESPONSE PACKET STRUCTURE

Byte | Type | Name | Description
0 | 0xC0 | type | Response packet
1 | 0x02 | length | Fixedlength payload (2)
2 | 0x04 | class | Command class: "motion"
3 | 0x02 | id | Command ID: "set_mode"
4 5 | uint16_t | result | Result code from command

5.1.2.1 Example Usage (Python)

# generate command packet only

packet = kglib.kg_cmd_motion_set_mode(index, mode)

# generate and send command

kglib.send_command(rxtx_obj, kglib.kg_cmd_motion_set_mode(index, mode))

# send command and wait for captured response

response = kglib.send_and_return(rxtx_obj, kglib.kg_cmd_motion_set_mode(index, mode), \ timeout)
print("kg_rsp_motion_set_mode: { result: %04X }" % (response['payload']['result']))

# create separate callback for response

def my_kg_rsp_motion_set_mode(sender, args):
print("kg_rsp_motion_set_mode: { result: %04X }" % (args['result']))

# assign separate callback function to appropriate KGLib response handler collection kglib.kg_rsp_motion_set_mode += my_kg_rsp_motion_set_mode

## 5.2 Events

### 5.2.1 motion_mode [ 80 02 04 01 ... ]

Indicates that a motion sensor's mode has changed.

## INCOMING EVENT PACKET STRUCTURE

Byte | Type | Name | Description
0 | 0x80 | type | Event packet
1 | 0x02 | length | Fixedlength payload (2)
2 | 0x04 | class | Event class: "motion"

3 | 0x01 | id | Event ID: "mode"
4 | uint8_t | index | Affected motion sensor
5 | uint8_t | mode | New motion sensor mode

5.2.1.1 Example Usage (Python)

# create callback for event

def my_kg_evt_motion_mode(sender, args):
print("kg_evt_motion_mode: { index: %02X, mode: %02X }" % (args['index'], args['mode']))

# assign callback function to appropriate KGLib event handler collection kglib.kg_evt_motion_mode += my_kg_evt_motion_mode

### 5.2.2 motion_data [ 80 03+ 04 02 ... ]

Indicates that a motion sensor's measurement data has been updated.

## INCOMING EVENT PACKET STRUCTURE

Byte | Type | Name | Description
0 | 0x80 | type | Event packet
1 | 0x03+ | length | Variablelength payload (3+)
2 | 0x04 | class | Event class: "motion"
3 | 0x02 | id | Event ID: "data"
4 | uint8_t | index | Relevant motion sensor
5 | uint8_t | flags | Flags indicating which measurement data is represented
6 | uint8_t[] | data | New measurement data

5.2.2.1 Example Usage (Python)

# create callback for event

def my_kg_evt_motion_data(sender, args):
print("kg_evt_motion_data: { index: %02X, flags: %02X, data: %s }" % (args['index'], \ args['flags'], ' '.join(['%02X' % b for b in args['data']])))

# assign callback function to appropriate KGLib event handler collection kglib.kg_evt_motion_data += my_kg_evt_motion_data

### 5.2.3 motion_state [ 80 02 04 03 ... ]

Motion state change detected, such as 'still' or 'moving'.

## INCOMING EVENT PACKET STRUCTURE

Byte | Type | Name | Description
0 | 0x80 | type | Event packet
1 | 0x02 | length | Fixedlength payload (2)
2 | 0x04 | class | Event class: "motion"
3 | 0x03 | id | Event ID: "state"
4 | uint8_t | index | Relevant motion sensor
5 | uint8_t | state | Type of motion state detected

5.2.3.1 Example Usage (Python)

# create callback for event

def my_kg_evt_motion_state(sender, args):
print("kg_evt_motion_state: { index: %02X, state: %02X }" % (args['index'], \ args['state']))

# assign callback function to appropriate KGLib event handler collection kglib.kg_evt_motion_state += my_kg_evt_motion_state

# 6 Bluetooth class (ID = 8)

Bluetooth commands and events control and report on the wireless functionality.

## 6.1 Commands

### 6.1.1 bluetooth_get_mode [ C0 00 08 01 ]

Get current mode for Bluetooth subsystem.

## OUTGOING COMMAND PACKET STRUCTURE

Byte | Type | Name | Description
0 | 0xC0 | type | Command packet
1 | 0x00 | length | No payload
2 | 0x08 | class | Command class: "bluetooth"
3 | 0x01 | id | Command ID: "get_mode"

## INCOMING RESPONSE PACKET STRUCTURE

Byte | Type | Name | Description
0 | 0xC0 | type | Response packet
1 | 0x03 | length | Fixedlength payload (3)
2 | 0x08 | class | Command class: "bluetooth"
3 | 0x01 | id | Command ID: "get_mode"
4 5 | uint16_t | result | Result code from command
6 | uint8_t | mode | Current Bluetooth mode

6.1.1.1 Example Usage (Python)

# generate command packet only

packet = kglib.kg_cmd_bluetooth_get_mode()

# generate and send command

kglib.send_command(rxtx_obj, kglib.kg_cmd_bluetooth_get_mode())

# send command and wait for captured response

response = kglib.send_and_return(rxtx_obj, kglib.kg_cmd_bluetooth_get_mode(), timeout) print("kg_rsp_bluetooth_get_mode: { result: %04X, mode: %02X }" % \ (response['payload']['result'], response['payload']['mode']))

# create separate callback for response

def my_kg_rsp_bluetooth_get_mode(sender, args):
print("kg_rsp_bluetooth_get_mode: { result: %04X, mode: %02X }" % (args['result'], \ args['mode']))

# assign separate callback function to appropriate KGLib response handler collection kglib.kg_rsp_bluetooth_get_mode += my_kg_rsp_bluetooth_get_mode

### 6.1.2 bluetooth_set_mode [ C0 01 08 02 ... ]

Set new mode for Bluetooth subsystem.

## OUTGOING COMMAND PACKET STRUCTURE

Byte | Type | Name | Description
0 | 0xC0 | type | Command packet
1 | 0x01 | length | Fixedlength payload (1)
2 | 0x08 | class | Command class: "bluetooth"
3 | 0x02 | id | Command ID: "set_mode"
4 | uint8_t | mode | New Bluetooth mode to set

## INCOMING RESPONSE PACKET STRUCTURE

Byte | Type | Name | Description
0 | 0xC0 | type | Response packet
1 | 0x02 | length | Fixedlength payload (2)
2 | 0x08 | class | Command class: "bluetooth"
3 | 0x02 | id | Command ID: "set_mode"
4 5 | uint16_t | result | Result code from command

6.1.2.1 Example Usage (Python)

# generate command packet only

packet = kglib.kg_cmd_bluetooth_set_mode(mode)

# generate and send command

kglib.send_command(rxtx_obj, kglib.kg_cmd_bluetooth_set_mode(mode))

# send command and wait for captured response

response = kglib.send_and_return(rxtx_obj, kglib.kg_cmd_bluetooth_set_mode(mode), timeout) print("kg_rsp_bluetooth_set_mode: { result: %04X }" % (response['payload']['result']))

# create separate callback for response

def my_kg_rsp_bluetooth_set_mode(sender, args):
print("kg_rsp_bluetooth_set_mode: { result: %04X }" % (args['result']))

# assign separate callback function to appropriate KGLib response handler collection kglib.kg_rsp_bluetooth_set_mode += my_kg_rsp_bluetooth_set_mode

### 6.1.3 bluetooth_reset [ C0 00 08 03 ]

Reset Bluetooth subsystem.

## OUTGOING COMMAND PACKET STRUCTURE

Byte | Type | Name | Description
0 | 0xC0 | type | Command packet
1 | 0x00 | length | No payload
2 | 0x08 | class | Command class: "bluetooth"
3 | 0x03 | id | Command ID: "reset"

## INCOMING RESPONSE PACKET STRUCTURE

Byte | Type | Name | Description
0 | 0xC0 | type | Response packet
1 | 0x02 | length | Fixedlength payload (2)
2 | 0x08 | class | Command class: "bluetooth"
3 | 0x03 | id | Command ID: "reset"
4 5 | uint16_t | result | Result code from command

6.1.3.1 Example Usage (Python)

# generate command packet only

packet = kglib.kg_cmd_bluetooth_reset()

# generate and send command

kglib.send_command(rxtx_obj, kglib.kg_cmd_bluetooth_reset())

# send command and wait for captured response

response = kglib.send_and_return(rxtx_obj, kglib.kg_cmd_bluetooth_reset(), timeout) print("kg_rsp_bluetooth_reset: { result: %04X }" % (response['payload']['result']))

# create separate callback for response

def my_kg_rsp_bluetooth_reset(sender, args):
print("kg_rsp_bluetooth_reset: { result: %04X }" % (args['result']))

# assign separate callback function to appropriate KGLib response handler collection kglib.kg_rsp_bluetooth_reset += my_kg_rsp_bluetooth_reset

### 6.1.4 bluetooth_get_mac [ C0 00 08 04 ]

Get local Bluetooth MAC address.

## OUTGOING COMMAND PACKET STRUCTURE

Byte | Type | Name | Description
0 | 0xC0 | type | Command packet
1 | 0x00 | length | No payload
2 | 0x08 | class | Command class: "bluetooth"
3 | 0x04 | id | Command ID: "get_mac"

## INCOMING RESPONSE PACKET STRUCTURE

Byte | Type | Name | Description
0 | 0xC0 | type | Response packet
1 | 0x08 | length | Fixedlength payload (8)
2 | 0x08 | class | Command class: "bluetooth"
3 | 0x04 | id | Command ID: "get_mac"
4 5 | uint16_t | result | Result code from command
6 11 | macaddr_t | address | Local sixbyte Bluetooth MAC address

6.1.4.1 Example Usage (Python)

# generate command packet only

packet = kglib.kg_cmd_bluetooth_get_mac()

# generate and send command

kglib.send_command(rxtx_obj, kglib.kg_cmd_bluetooth_get_mac())

# send command and wait for captured response

response = kglib.send_and_return(rxtx_obj, kglib.kg_cmd_bluetooth_get_mac(), timeout) print("kg_rsp_bluetooth_get_mac: { result: %04X, address: %s }" % \ (response['payload']['result'], ' '.join(['%02X' % b for b in' \ ' response['payload']['address']])))

# create separate callback for response

def my_kg_rsp_bluetooth_get_mac(sender, args):
print("kg_rsp_bluetooth_get_mac: { result: %04X, address: %s }" % (args['result'], '' \ ' '.join(['%02X' % b for b in args['address']])))

# assign separate callback function to appropriate KGLib response handler collection kglib.kg_rsp_bluetooth_get_mac += my_kg_rsp_bluetooth_get_mac

### 6.1.5 bluetooth_get_pairings [ C0 00 08 05 ]

Get a list of all paired devices. The response will be followed by one 'bluetooth_pairing_status' event for each existing pairing entry.

## OUTGOING COMMAND PACKET STRUCTURE

Byte | Type | Name | Description
0 | 0xC0 | type | Command packet
1 | 0x00 | length | No payload
2 | 0x08 | class | Command class: "bluetooth"
3 | 0x05 | id | Command ID: "get_pairings"

## INCOMING RESPONSE PACKET STRUCTURE

Byte | Type | Name | Description
0 | 0xC0 | type | Response packet
1 | 0x03 | length | Fixedlength payload (3)
2 | 0x08 | class | Command class: "bluetooth"
3 | 0x05 | id | Command ID: "get_pairings"
4 5 | uint16_t | result | Result code from command
6 | uint8_t | count | Number of paired devices

6.1.5.1 Example Usage (Python)

# generate command packet only

packet = kglib.kg_cmd_bluetooth_get_pairings()

# generate and send command

kglib.send_command(rxtx_obj, kglib.kg_cmd_bluetooth_get_pairings())

# send command and wait for captured response

response = kglib.send_and_return(rxtx_obj, kglib.kg_cmd_bluetooth_get_pairings(), timeout)

print("kg_rsp_bluetooth_get_pairings: { result: %04X, count: %02X }" % \ (response['payload']['result'], response['payload']['count']))

# create separate callback for response

def my_kg_rsp_bluetooth_get_pairings(sender, args): print("kg_rsp_bluetooth_get_pairings: { result: %04X, count: %02X }" % \ (args['result'], args['count']))

# assign separate callback function to appropriate KGLib response handler collection kglib.kg_rsp_bluetooth_get_pairings += my_kg_rsp_bluetooth_get_pairings

### 6.1.6 bluetooth_discover [ C0 01 08 06 ... ]

Perform Bluetooth inquiry to locate nearby devices. The response will be followed by one 'bluetooth_inquiry_response' event for each device that is discovered during the inquiry. Once the inquiry is finished, the 'bluetooth_inquiry_complete' event will occur.

## OUTGOING COMMAND PACKET STRUCTURE

Byte | Type | Name | Description
0 | 0xC0 | type | Command packet
1 | 0x01 | length | Fixedlength payload (1)
2 | 0x08 | class | Command class: "bluetooth"
3 | 0x06 | id | Command ID: "discover"
4 | uint8_t | duration | Number of seconds to run discovery process

## INCOMING RESPONSE PACKET STRUCTURE

Byte | Type | Name | Description
0 | 0xC0 | type | Response packet
1 | 0x02 | length | Fixedlength payload (2)
2 | 0x08 | class | Command class: "bluetooth"
3 | 0x06 | id | Command ID: "discover"
4 5 | uint16_t | result | Result code from command

6.1.6.1 Example Usage (Python)

# generate command packet only

packet = kglib.kg_cmd_bluetooth_discover(duration)

# generate and send command

kglib.send_command(rxtx_obj, kglib.kg_cmd_bluetooth_discover(duration))

# send command and wait for captured response

response = kglib.send_and_return(rxtx_obj, kglib.kg_cmd_bluetooth_discover(duration), \ timeout)
print("kg_rsp_bluetooth_discover: { result: %04X }" % (response['payload']['result']))

# create separate callback for response

def my_kg_rsp_bluetooth_discover(sender, args):
print("kg_rsp_bluetooth_discover: { result: %04X }" % (args['result']))

# assign separate callback function to appropriate KGLib response handler collection kglib.kg_rsp_bluetooth_discover += my_kg_rsp_bluetooth_discover

### 6.1.7 bluetooth_pair [ C0 06 08 07 ... ]

Initiate pairing request to remote device. The response will be followed by a 'bluetooth_pairing_status' event upon success, or a 'bluetooth_pairing_failed' event if unsuccessful.

## OUTGOING COMMAND PACKET STRUCTURE

Byte | Type | Name | Description
0 | 0xC0 | type | Command packet
1 | 0x06 | length | Fixedlength payload (6)
2 | 0x08 | class | Command class: "bluetooth"
3 | 0x07 | id | Command ID: "pair"
4 9 | macaddr_t | address | Sixbyte Bluetooth MAC address of remote device to pair with

## INCOMING RESPONSE PACKET STRUCTURE

Byte | Type | Name | Description
0 | 0xC0 | type | Response packet
1 | 0x02 | length | Fixedlength payload (2)
2 | 0x08 | class | Command class: "bluetooth"
3 | 0x07 | id | Command ID: "pair"
4 5 | uint16_t | result | Result code from command

6.1.7.1 Example Usage (Python)

# generate command packet only

packet = kglib.kg_cmd_bluetooth_pair(address)

# generate and send command

kglib.send_command(rxtx_obj, kglib.kg_cmd_bluetooth_pair(address))

# send command and wait for captured response

response = kglib.send_and_return(rxtx_obj, kglib.kg_cmd_bluetooth_pair(address), timeout) print("kg_rsp_bluetooth_pair: { result: %04X }" % (response['payload']['result']))

# create separate callback for response

def my_kg_rsp_bluetooth_pair(sender, args):
print("kg_rsp_bluetooth_pair: { result: %04X }" % (args['result']))

# assign separate callback function to appropriate KGLib response handler collection kglib.kg_rsp_bluetooth_pair += my_kg_rsp_bluetooth_pair

### 6.1.8 bluetooth_delete_pairing [ C0 01 08 08 ... ]

Remove a specific pairing entry. Note that this will not actively close any Bluetooth connections to that device, if they are already open.

## OUTGOING COMMAND PACKET STRUCTURE

Byte | Type | Name | Description
0 | 0xC0 | type | Command packet
1 | 0x01 | length | Fixedlength payload (1)
2 | 0x08 | class | Command class: "bluetooth"

3 | 0x08 | id | Command ID: "delete_pairing"
4 | uint8_t | pairing | Index of pairing to delete

## INCOMING RESPONSE PACKET STRUCTURE

Byte | Type | Name | Description
0 | 0xC0 | type | Response packet
1 | 0x02 | length | Fixedlength payload (2)
2 | 0x08 | class | Command class: "bluetooth"
3 | 0x08 | id | Command ID: "delete_pairing"
4 5 | uint16_t | result | Result code from command

6.1.8.1 Example Usage (Python)

# generate command packet only

packet = kglib.kg_cmd_bluetooth_delete_pairing(pairing)

# generate and send command

kglib.send_command(rxtx_obj, kglib.kg_cmd_bluetooth_delete_pairing(pairing))

# send command and wait for captured response

response = kglib.send_and_return(rxtx_obj, kglib.kg_cmd_bluetooth_delete_pairing(pairing), \ timeout)
print("kg_rsp_bluetooth_delete_pairing: { result: %04X }" % (response['payload']['result']))

# create separate callback for response

def my_kg_rsp_bluetooth_delete_pairing(sender, args): print("kg_rsp_bluetooth_delete_pairing: { result: %04X }" % (args['result']))

# assign separate callback function to appropriate KGLib response handler collection kglib.kg_rsp_bluetooth_delete_pairing += my_kg_rsp_bluetooth_delete_pairing

### 6.1.9 bluetooth_clear_pairings [ C0 00 08 09 ]

Remove all pairing entries. Note that this will not immediately close any Bluetooth connections.

## OUTGOING COMMAND PACKET STRUCTURE

Byte | Type | Name | Description
0 | 0xC0 | type | Command packet
1 | 0x00 | length | No payload
2 | 0x08 | class | Command class: "bluetooth"
3 | 0x09 | id | Command ID: "clear_pairings"

## INCOMING RESPONSE PACKET STRUCTURE

Byte | Type | Name | Description
0 | 0xC0 | type | Response packet
1 | 0x02 | length | Fixedlength payload (2)
2 | 0x08 | class | Command class: "bluetooth"
3 | 0x09 | id | Command ID: "clear_pairings"

4 5 | uint16_t | result | Result code from command

6.1.9.1 Example Usage (Python)

# generate command packet only

packet = kglib.kg_cmd_bluetooth_clear_pairings()

# generate and send command

kglib.send_command(rxtx_obj, kglib.kg_cmd_bluetooth_clear_pairings())

# send command and wait for captured response

response = kglib.send_and_return(rxtx_obj, kglib.kg_cmd_bluetooth_clear_pairings(), timeout) print("kg_rsp_bluetooth_clear_pairings: { result: %04X }" % (response['payload']['result']))

# create separate callback for response

def my_kg_rsp_bluetooth_clear_pairings(sender, args): print("kg_rsp_bluetooth_clear_pairings: { result: %04X }" % (args['result']))

# assign separate callback function to appropriate KGLib response handler collection kglib.kg_rsp_bluetooth_clear_pairings += my_kg_rsp_bluetooth_clear_pairings

### 6.1.10 bluetooth_get_connections [ C0 00 08 0A ]

Get a list of all open or pending connections. The response will be followed by one 'bluetooth_connection_status' event for each open or pending connection.

## OUTGOING COMMAND PACKET STRUCTURE

Byte | Type | Name | Description
0 | 0xC0 | type | Command packet
1 | 0x00 | length | No payload
2 | 0x08 | class | Command class: "bluetooth"
3 | 0x0A | id | Command ID: "get_connections"

## INCOMING RESPONSE PACKET STRUCTURE

Byte | Type | Name | Description
0 | 0xC0 | type | Response packet
1 | 0x03 | length | Fixedlength payload (3)
2 | 0x08 | class | Command class: "bluetooth"
3 | 0x0A | id | Command ID: "get_connections"
4 5 | uint16_t | result | Result code from command
6 | uint8_t | count | Number of open or pending connections

6.1.10.1 Example Usage (Python)

# generate command packet only

packet = kglib.kg_cmd_bluetooth_get_connections()

# generate and send command

kglib.send_command(rxtx_obj, kglib.kg_cmd_bluetooth_get_connections())

# send command and wait for captured response

response = kglib.send_and_return(rxtx_obj, kglib.kg_cmd_bluetooth_get_connections(), \ timeout)
print("kg_rsp_bluetooth_get_connections: { result: %04X, count: %02X }" % \ (response['payload']['result'], response['payload']['count']))

# create separate callback for response

def my_kg_rsp_bluetooth_get_connections(sender, args): print("kg_rsp_bluetooth_get_connections: { result: %04X, count: %02X }" % \ (args['result'], args['count']))

# assign separate callback function to appropriate KGLib response handler collection kglib.kg_rsp_bluetooth_get_connections += my_kg_rsp_bluetooth_get_connections

### 6.1.11 bluetooth_connect [ C0 02 08 0B ... ]

Attempt to open a connection to a specific paired device using a specific profile. This will be followed by a 'bluetooth_connection_status' event once the handle has been allocated.

## OUTGOING COMMAND PACKET STRUCTURE

Byte | Type | Name | Description
0 | 0xC0 | type | Command packet
1 | 0x02 | length | Fixedlength payload (2)
2 | 0x08 | class | Command class: "bluetooth"
3 | 0x0B | id | Command ID: "connect"
4 | uint8_t | pairing | Index of pairing to use
5 | uint8_t | profile | Profile to use for connection

## INCOMING RESPONSE PACKET STRUCTURE

Byte | Type | Name | Description
0 | 0xC0 | type | Response packet
1 | 0x02 | length | Fixedlength payload (2)
2 | 0x08 | class | Command class: "bluetooth"
3 | 0x0B | id | Command ID: "connect"
4 5 | uint16_t | result | Result code from command

6.1.11.1 Example Usage (Python)

# generate command packet only

packet = kglib.kg_cmd_bluetooth_connect(pairing, profile)

# generate and send command

kglib.send_command(rxtx_obj, kglib.kg_cmd_bluetooth_connect(pairing, profile))

# send command and wait for captured response

response = kglib.send_and_return(rxtx_obj, kglib.kg_cmd_bluetooth_connect(pairing, \ profile), timeout)
print("kg_rsp_bluetooth_connect: { result: %04X }" % (response['payload']['result']))

# create separate callback for response

def my_kg_rsp_bluetooth_connect(sender, args):

print("kg_rsp_bluetooth_connect: { result: %04X }" % (args['result']))

# assign separate callback function to appropriate KGLib response handler collection kglib.kg_rsp_bluetooth_connect += my_kg_rsp_bluetooth_connect

### 6.1.12 bluetooth_disconnect [ C0 01 08 0C ... ]

Close a specific Bluetooth connection.

## OUTGOING COMMAND PACKET STRUCTURE

Byte | Type | Name | Description
0 | 0xC0 | type | Command packet
1 | 0x01 | length | Fixedlength payload (1)
2 | 0x08 | class | Command class: "bluetooth"
3 | 0x0C | id | Command ID: "disconnect"
4 | uint8_t | handle | Link ID of connection to close

## INCOMING RESPONSE PACKET STRUCTURE

Byte | Type | Name | Description
0 | 0xC0 | type | Response packet
1 | 0x02 | length | Fixedlength payload (2)
2 | 0x08 | class | Command class: "bluetooth"
3 | 0x0C | id | Command ID: "disconnect"
4 5 | uint16_t | result | Result code from command

6.1.12.1 Example Usage (Python)

# generate command packet only

packet = kglib.kg_cmd_bluetooth_disconnect(handle)

# generate and send command

kglib.send_command(rxtx_obj, kglib.kg_cmd_bluetooth_disconnect(handle))

# send command and wait for captured response

response = kglib.send_and_return(rxtx_obj, kglib.kg_cmd_bluetooth_disconnect(handle), \ timeout)
print("kg_rsp_bluetooth_disconnect: { result: %04X }" % (response['payload']['result']))

# create separate callback for response

def my_kg_rsp_bluetooth_disconnect(sender, args):
print("kg_rsp_bluetooth_disconnect: { result: %04X }" % (args['result']))

# assign separate callback function to appropriate KGLib response handler collection kglib.kg_rsp_bluetooth_disconnect += my_kg_rsp_bluetooth_disconnect

## 6.2 Events

### 6.2.1 bluetooth_mode [ 80 01 08 01 ... ]

Indicates that the Bluetooth mode has been changed.

## INCOMING EVENT PACKET STRUCTURE

Byte | Type | Name | Description
0 | 0x80 | type | Event packet
1 | 0x01 | length | Fixedlength payload (1)
2 | 0x08 | class | Event class: "bluetooth"
3 | 0x01 | id | Event ID: "mode"
4 | uint8_t | mode | New Bluetooth connectivity mode

6.2.1.1 Example Usage (Python)

# create callback for event

def my_kg_evt_bluetooth_mode(sender, args): print("kg_evt_bluetooth_mode: { mode: %02X }" % (args['mode']))

# assign callback function to appropriate KGLib event handler collection kglib.kg_evt_bluetooth_mode += my_kg_evt_bluetooth_mode

### 6.2.2 bluetooth_ready [ 80 00 08 02 ]

Indicates that the Bluetooth subsystem is ready for use.

## INCOMING EVENT PACKET STRUCTURE

Byte | Type | Name | Description
0 | 0x80 | type | Event packet
1 | 0x00 | length | No payload
2 | 0x08 | class | Event class: "bluetooth"
3 | 0x02 | id | Event ID: "ready"

6.2.2.1 Example Usage (Python)

# create callback for event

def my_kg_evt_bluetooth_ready(sender, args): print("kg_evt_bluetooth_ready: { }")

# assign callback function to appropriate KGLib event handler collection kglib.kg_evt_bluetooth_ready += my_kg_evt_bluetooth_ready

### 6.2.3 bluetooth_inquiry_response [ 80 0D+ 08 03 ... ]

Indicates that a new device has been paired.

## INCOMING EVENT PACKET STRUCTURE

Byte | Type | Name | Description
0 | 0x80 | type | Event packet
1 | 0x0D+ | length | Variablelength payload (13+)
2 | 0x08 | class | Event class: "bluetooth"
3 | 0x03 | id | Event ID: "inquiry_response"
4 9 | macaddr_t | address | Sixbyte Bluetooth MAC address of remote device
10 12 | btcod_t | cod | Threebyte Bluetooth Classof-Device value

13 | int8_t | rssi | RSSI value from discovered device
14 | uint8_t | status | Status within inquiry process
15 | uint8_t | pairing | Index of device in pairing list (0xFF if not paired)
16 | uint8_t[] | name | Friendly name of remote device (if available)

6.2.3.1 Example Usage (Python)

# create callback for event

def my_kg_evt_bluetooth_inquiry_response(sender, args): print("kg_evt_bluetooth_inquiry_response: { address: %s, cod: %s, rssi: %02X, status:" \ " %02X, pairing: %02X, name: %s }" % (' '.join(['%02X' % b for b in' \
' args['address']]), ' '.join(['%02X' % b for b in args['cod']]),' \
' args['rssi'], args['status'], args['pairing'], ' '.join(['%02X' % b for b in \ args['name']])))

# assign callback function to appropriate KGLib event handler collection kglib.kg_evt_bluetooth_inquiry_response += my_kg_evt_bluetooth_inquiry_response

### 6.2.4 bluetooth_inquiry_complete [ 80 01 08 04 ... ]

Indicates that an ongoing Bluetooth discovery process has finished.

## INCOMING EVENT PACKET STRUCTURE

Byte | Type | Name | Description
0 | 0x80 | type | Event packet
1 | 0x01 | length | Fixedlength payload (1)
2 | 0x08 | class | Event class: "bluetooth"
3 | 0x04 | id | Event ID: "inquiry_complete"
4 | uint8_t | count | Total number of devices found during discovery

6.2.4.1 Example Usage (Python)

# create callback for event

def my_kg_evt_bluetooth_inquiry_complete(sender, args): print("kg_evt_bluetooth_inquiry_complete: { count: %02X }" % (args['count']))

# assign callback function to appropriate KGLib event handler collection kglib.kg_evt_bluetooth_inquiry_complete += my_kg_evt_bluetooth_inquiry_complete

### 6.2.5 bluetooth_pairing_status [ 80 0B+ 08 05 ... ]

Provides a single pairing entry detailed status record.

## INCOMING EVENT PACKET STRUCTURE

Byte | Type | Name | Description
0 | 0x80 | type | Event packet
1 | 0x0B+ | length | Variablelength payload (11+)
2 | 0x08 | class | Event class: "bluetooth"
3 | 0x05 | id | Event ID: "pairing_status"
4 | uint8_t | pairing | Index of device in pairing list

5 10 | macaddr_t | address | Sixbyte Bluetooth MAC address of remote device
11 | uint8_t | priority | Autoconnection priority
12 | uint8_t | profiles_supported | Bitmask of supported profiles
13 | uint8_t | profiles_active | Bitmask of active profiles
14 | uint8_t[] | handle_list | Handles for all active Bluetooth profile connections

6.2.5.1 Example Usage (Python)

# create callback for event

def my_kg_evt_bluetooth_pairing_status(sender, args): print("kg_evt_bluetooth_pairing_status: { pairing: %02X, address: %s, priority: %02X," \ " profiles_supported: %02X, profiles_active: %02X, handle_list: %s }" %" \ " (args['pairing'], ' '.join(['%02X' % b for b in args['address']]),' \
' args['priority'], args['profiles_supported'], args['profiles_active'], ' \ '.join(['%02X' % b for b in args['handle_list']])))

# assign callback function to appropriate KGLib event handler collection kglib.kg_evt_bluetooth_pairing_status += my_kg_evt_bluetooth_pairing_status

### 6.2.6 bluetooth_pairing_failed [ 80 06 08 06 ... ]

Indicates that a pending pair attempt has failed.

## INCOMING EVENT PACKET STRUCTURE

Byte | Type | Name | Description
0 | 0x80 | type | Event packet
1 | 0x06 | length | Fixedlength payload (6)
2 | 0x08 | class | Event class: "bluetooth"
3 | 0x06 | id | Event ID: "pairing_failed"
4 9 | macaddr_t | address | Sixbyte Bluetooth MAC address which failed pairing attempt

6.2.6.1 Example Usage (Python)

# create callback for event

def my_kg_evt_bluetooth_pairing_failed(sender, args): print("kg_evt_bluetooth_pairing_failed: { address: %s }" % (' '.join(['%02X' % b for b \ in args['address']])))

# assign callback function to appropriate KGLib event handler collection kglib.kg_evt_bluetooth_pairing_failed += my_kg_evt_bluetooth_pairing_failed

### 6.2.7 bluetooth_pairings_cleared [ 80 00 08 07 ]

Indicates that all pairings have been removed.

## INCOMING EVENT PACKET STRUCTURE

Byte | Type | Name | Description
0 | 0x80 | type | Event packet
1 | 0x00 | length | No payload
2 | 0x08 | class | Event class: "bluetooth"
3 | 0x07 | id | Event ID: "pairings_cleared"

6.2.7.1 Example Usage (Python)

# create callback for event

def my_kg_evt_bluetooth_pairings_cleared(sender, args): print("kg_evt_bluetooth_pairings_cleared: { }")

# assign callback function to appropriate KGLib event handler collection kglib.kg_evt_bluetooth_pairings_cleared += my_kg_evt_bluetooth_pairings_cleared

### 6.2.8 bluetooth_connection_status [ 80 0A 08 08 ... ]

Indicates that a paired device has connected.

## INCOMING EVENT PACKET STRUCTURE

Byte | Type | Name | Description
0 | 0x80 | type | Event packet
1 | 0x0A | length | Fixedlength payload (10)
2 | 0x08 | class | Event class: "bluetooth"
3 | 0x08 | id | Event ID: "connection_status"
4 | uint8_t | handle | Connection handle
5 10 | macaddr_t | address | Sixbyte Bluetooth MAC address of remote device
11 | uint8_t | pairing | Index of device in pairing list
12 | uint8_t | profile | Bluetooth profile used for this connection
13 | uint8_t | status | Status

6.2.8.1 Example Usage (Python)

# create callback for event

def my_kg_evt_bluetooth_connection_status(sender, args): print("kg_evt_bluetooth_connection_status: { handle: %02X, address: %s, pairing:" \ " %02X, profile: %02X, status: %02X }" % (args['handle'], ' '.join(['%02X' %' \ ' b for b in args['address']]), args['pairing'], args['profile'], \ args['status']))

# assign callback function to appropriate KGLib event handler collection kglib.kg_evt_bluetooth_connection_status += my_kg_evt_bluetooth_connection_status

### 6.2.9 bluetooth_connection_closed [ 80 03 08 09 ... ]

Indicates that an active connection has been closed.

## INCOMING EVENT PACKET STRUCTURE

Byte | Type | Name | Description
0 | 0x80 | type | Event packet
1 | 0x03 | length | Fixedlength payload (3)
2 | 0x08 | class | Event class: "bluetooth"
3 | 0x09 | id | Event ID: "connection_closed"
4 | uint8_t | handle | Connection handle
5 6 | uint16_t | reason | Reason for connection closure

6.2.9.1 Example Usage (Python)

# create callback for event

def my_kg_evt_bluetooth_connection_closed(sender, args): print("kg_evt_bluetooth_connection_closed: { handle: %02X, reason: %04X }" % \ (args['handle'], args['reason']))

# assign callback function to appropriate KGLib event handler collection kglib.kg_evt_bluetooth_connection_closed += my_kg_evt_bluetooth_connection_closed

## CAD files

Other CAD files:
models/3d-axis-template.skp

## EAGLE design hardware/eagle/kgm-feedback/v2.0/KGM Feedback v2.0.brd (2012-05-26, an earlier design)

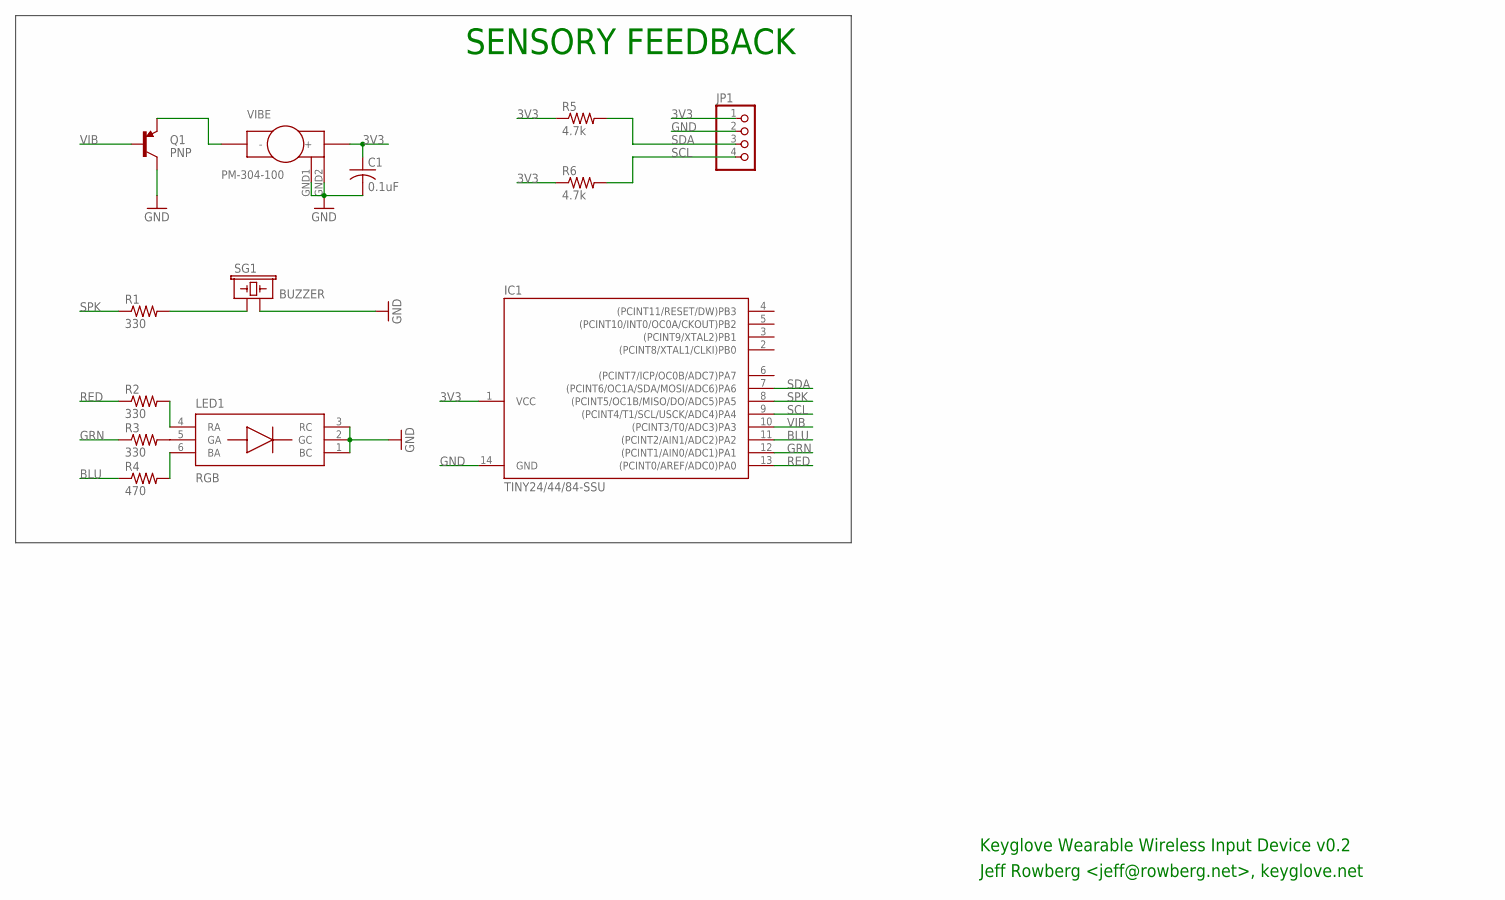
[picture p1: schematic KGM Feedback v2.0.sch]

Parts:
C1: 0.1uF; C0603
IC1: TINY24/44/84-SSU; SOIC14
JP1: PINHD-1X4; 1X04
LED1: RGB; PLCC-6
Q1: PNP; SOT23-3
R1, R2, R3: 330; R0603
R4: 470; R0603
R5, R6: 4.7k; R0603
SG1: BUZZER; BUZZER-CMT1102
VIBE: PM-304-100

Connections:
3V3: C1.1, IC1.1 (VCC), JP1.1, R5.1, R6.1, VIBE.+
BLU: IC1.11 ((PCINT2/AIN1/ADC2)PA2), R4.1
GND: C1.2, IC1.14 (GND), JP1.2, LED1.1 (BC), LED1.2 (GC), LED1.3 (RC), Q1.3 (C), SG1.2, VIBE.GND1 (GND), VIBE.GND2 (GND)
GRN: IC1.12 ((PCINT1/AIN0/ADC1)PA1), R3.1
unnamed: R1.2, SG1.1
unnamed: LED1.5 (GA), R3.2
unnamed: LED1.4 (RA), R2.2
unnamed: LED1.6 (BA), R4.2
unnamed: Q1.2 (E), VIBE.-
RED: IC1.13 ((PCINT0/AREF/ADC0)PA0), R2.1
SCL: IC1.9 ((PCINT4/T1/SCL/USCK/ADC4)PA4), JP1.4, R6.2
SDA: IC1.7 ((PCINT6/OC1A/SDA/MOSI/ADC6)PA6), JP1.3, R5.2
SPK: IC1.8 ((PCINT5/OC1B/MISO/DO/ADC5)PA5), R1.1
VIB: IC1.10 ((PCINT3/T0/ADC3)PA3), Q1.1 (B)

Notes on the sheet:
SENSORY FEEDBACK
Keyglove Wearable Wireless Input Device v0.2
Jeff Rowberg <jeff@rowberg.net>, keyglove.net

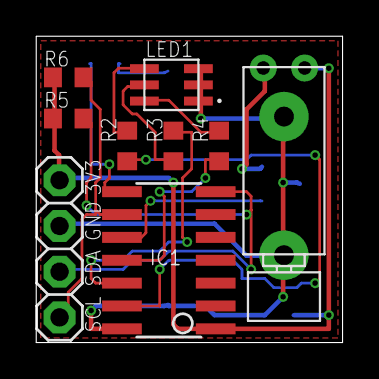
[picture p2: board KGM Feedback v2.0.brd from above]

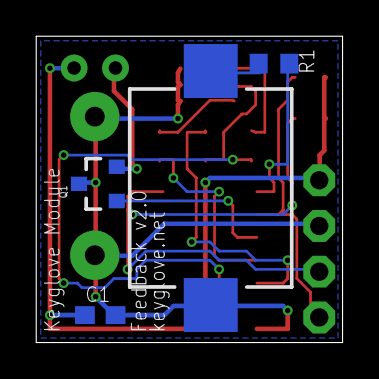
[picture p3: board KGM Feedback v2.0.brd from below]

Board: 2 copper layers, 17.0 x 17.0 mm, 13 parts (4 on the bottom side), 14 nets.

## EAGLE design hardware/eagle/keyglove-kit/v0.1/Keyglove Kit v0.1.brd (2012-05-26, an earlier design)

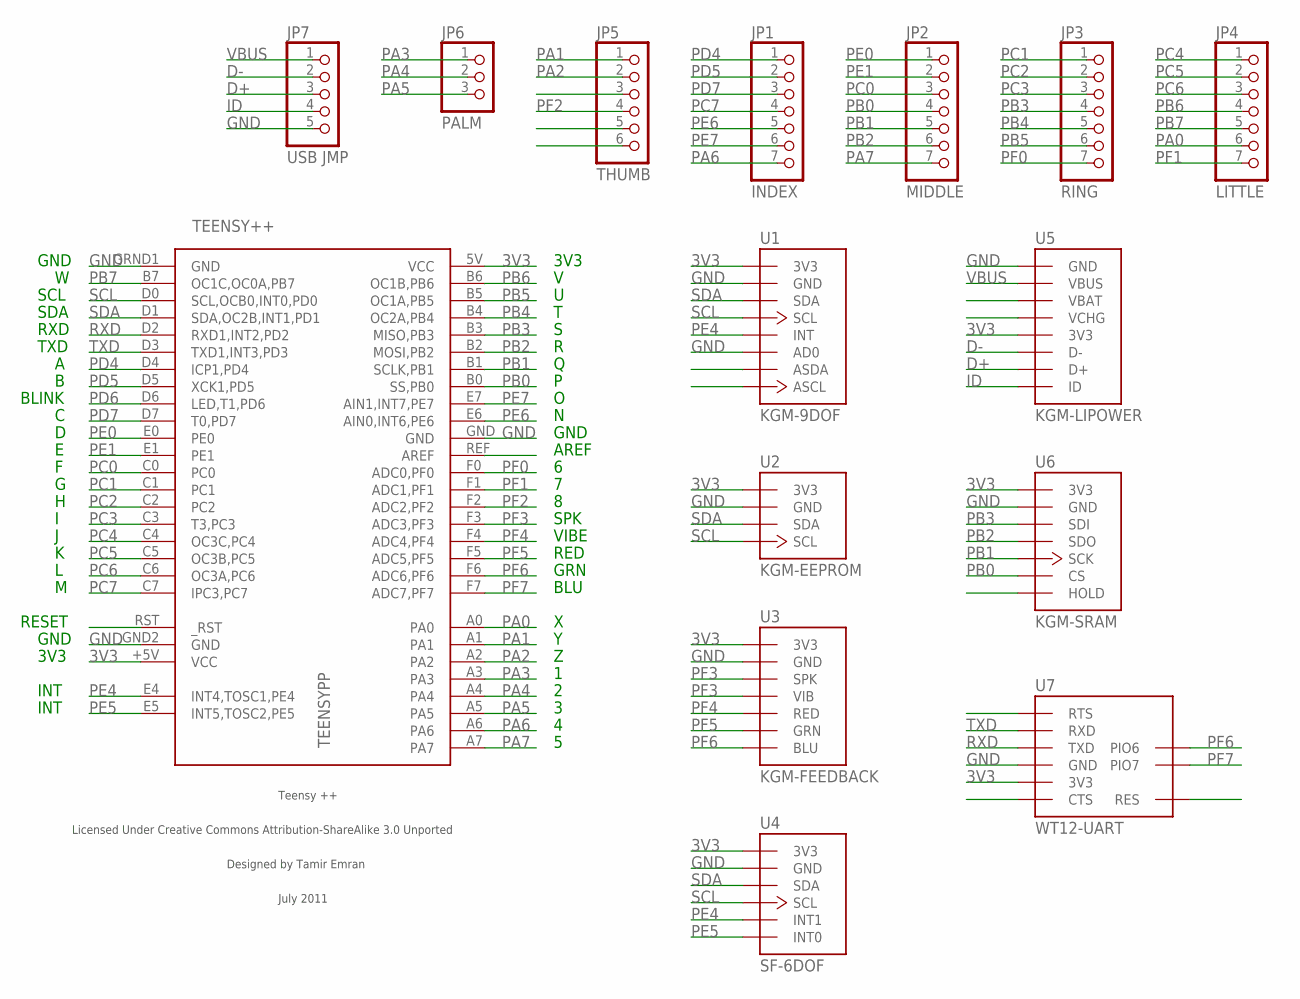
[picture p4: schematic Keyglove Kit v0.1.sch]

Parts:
JP1: INDEX; 1X07
JP2: MIDDLE; 1X07
JP3: RING; 1X07
JP4: LITTLE; 1X07
JP5: THUMB; 1X06
JP6: PALM; 1X03
JP7: USB JMP; 1X05
TEENSY++: TEENSYPP
U1: KGM-9DOF
U2: KGM-EEPROM
U3: KGM-FEEDBACK
U4: SF-6DOF
U5: KGM-LIPOWER
U6: KGM-SRAM
U7: WT12-UART

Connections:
3V3: TEENSY++.5V (VCC), TEENSY++.+5V (VCC), U1.3V3, U2.3V3, U3.3V3, U4.3V3, U5.3V3, U6.3V3, U7.3V3
D+: JP7.3, U5.D+
D-: JP7.2, U5.D-
GND: JP7.5, TEENSY++.GND, TEENSY++.GND2 (GND), TEENSY++.GRND1 (GND), U1.AD0, U1.GND, U2.GND, U3.GND, U4.GND, U5.GND, U6.GND, U7.GND
ID: JP7.4, U5.ID
PA0: JP4.6, TEENSY++.A0
PA1: JP5.1, TEENSY++.A1
PA2: JP5.2, TEENSY++.A2
PA3: JP6.1, TEENSY++.A3
PA4: JP6.2, TEENSY++.A4
PA5: JP6.3, TEENSY++.A5
PA6: JP1.7, TEENSY++.A6
PA7: JP2.7, TEENSY++.A7
PB0: JP2.4, TEENSY++.B0 (SS,PB0), U6.CS
PB1: JP2.5, TEENSY++.B1 (SCLK,PB1), U6.SCK
PB2: JP2.6, TEENSY++.B2 (MOSI,PB2), U6.SDO
PB3: JP3.4, TEENSY++.B3 (MISO,PB3), U6.SDI
PB4: JP3.5, TEENSY++.B4 (OC2A,PB4)
PB5: JP3.6, TEENSY++.B5 (OC1A,PB5)
PB6: JP4.4, TEENSY++.B6 (OC1B,PB6)
PB7: JP4.5, TEENSY++.B7 (OC1C,OC0A,PB7)
PC0: JP2.3, TEENSY++.C0
PC1: JP3.1, TEENSY++.C1
PC2: JP3.2, TEENSY++.C2
PC3: JP3.3, TEENSY++.C3 (T3,PC3)
PC4: JP4.1, TEENSY++.C4 (OC3C,PC4)
PC5: JP4.2, TEENSY++.C5 (OC3B,PC5)
PC6: JP4.3, TEENSY++.C6 (OC3A,PC6)
PC7: JP1.4, TEENSY++.C7 (IPC3,PC7)
PD4: JP1.1, TEENSY++.D4 (ICP1,PD4)
PD5: JP1.2, TEENSY++.D5 (XCK1,PD5)
PD6: TEENSY++.D6 (LED,T1,PD6)
PD7: JP1.3, TEENSY++.D7 (T0,PD7)
PE0: JP2.1, TEENSY++.E0
PE1: JP2.2, TEENSY++.E1
PE4: TEENSY++.E4 (INT4,TOSC1,PE4), U1.INT, U4.INT1
PE5: TEENSY++.E5 (INT5,TOSC2,PE5), U4.INT0
PE6: JP1.5, TEENSY++.E6 (AIN0,INT6,PE6)
PE7: JP1.6, TEENSY++.E7 (AIN1,INT7,PE7)
PF0: JP3.7, TEENSY++.F0 (ADC0,PF0)
PF1: JP4.7, TEENSY++.F1 (ADC1,PF1)
PF2: JP5.4, TEENSY++.F2 (ADC2,PF2)
PF3: TEENSY++.F3 (ADC3,PF3), U3.SPK, U3.VIB
PF4: TEENSY++.F4 (ADC4,PF4), U3.RED
PF5: TEENSY++.F5 (ADC5,PF5), U3.GRN
PF6: TEENSY++.F6 (ADC6,PF6), U3.BLUE (BLU), U7.PIO6
PF7: TEENSY++.F7 (ADC7,PF7), U7.PIO7
RXD: TEENSY++.D2 (RXD1,INT2,PD2), U7.TXD
SCL: TEENSY++.D0 (SCL,OCB0,INT0,PD0), U1.SCL, U2.SCL, U4.SCL
SDA: TEENSY++.D1 (SDA,OC2B,INT1,PD1), U1.SDA, U2.SDA, U4.SDA
TXD: TEENSY++.D3 (TXD1,INT3,PD3), U7.RXD
VBUS: JP7.1, U5.VBUS

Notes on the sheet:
SCL
SDA
RXD
TXD
BLINK
RESET
GND
3V3
INT
AREF
SPK
VIBE
RED
GRN
BLU

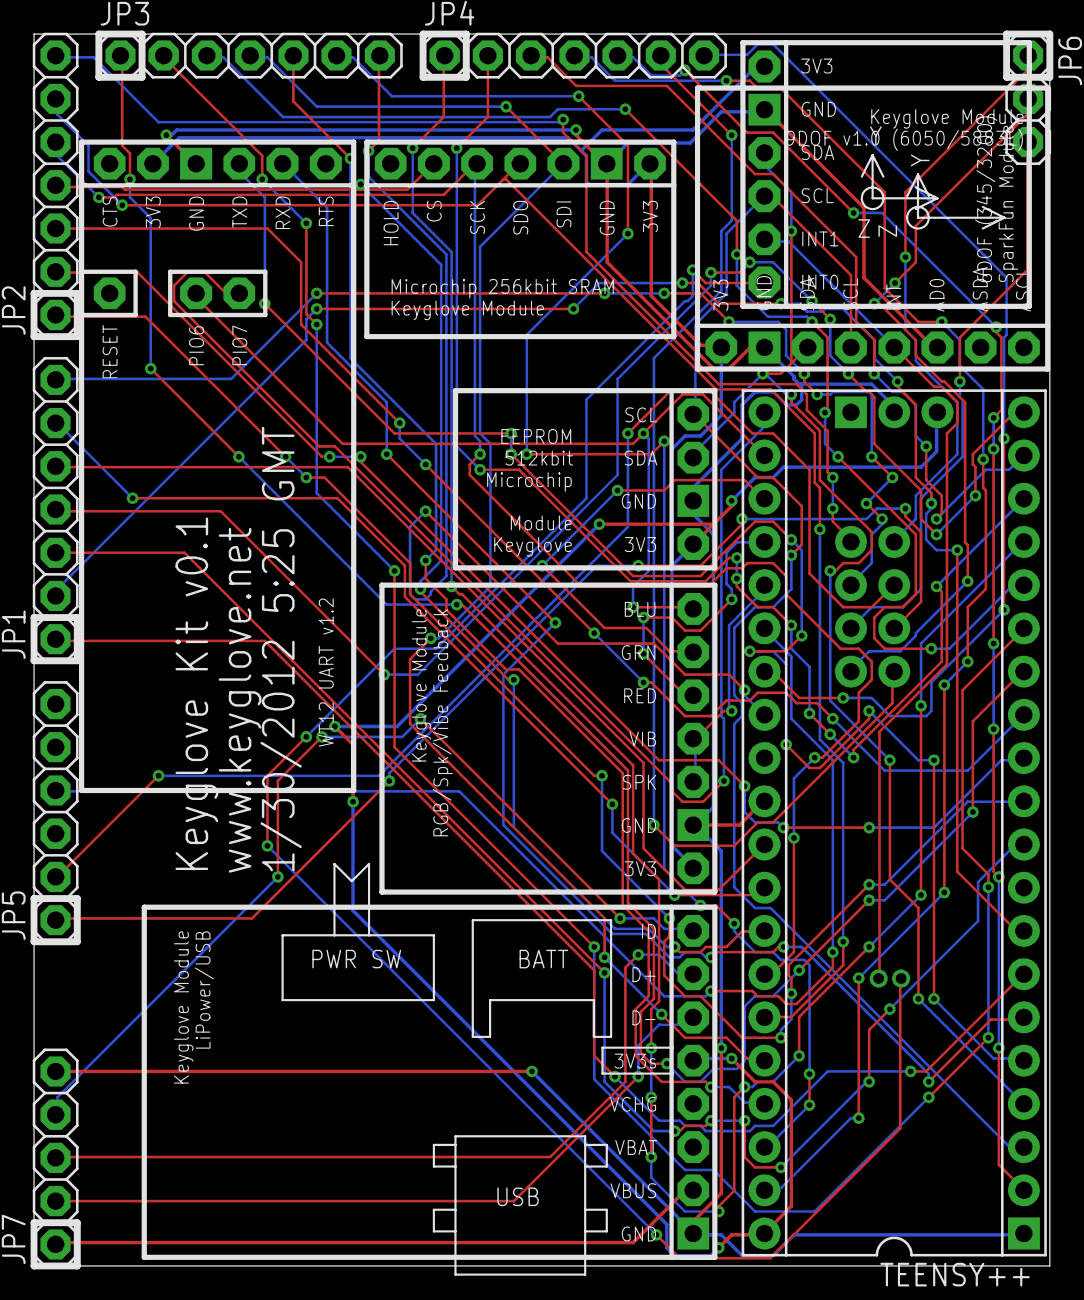
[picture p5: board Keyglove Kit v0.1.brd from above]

Board: 2 copper layers, 59.7 x 72.4 mm, 15 parts (0 on the bottom side), 51 nets.

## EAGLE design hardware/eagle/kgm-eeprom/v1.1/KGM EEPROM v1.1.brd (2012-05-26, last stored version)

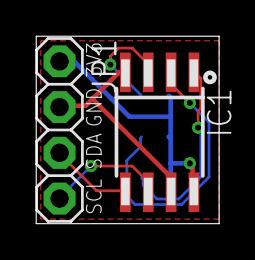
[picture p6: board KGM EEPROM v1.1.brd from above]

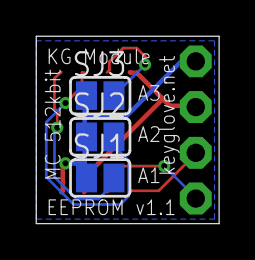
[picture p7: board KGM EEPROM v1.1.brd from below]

Board: 2 copper layers, 10.2 x 10.4 mm, 5 parts (3 on the bottom side), 7 nets.

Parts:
IC1: 24LC512SM; SO-08M
JP1: CONN; 1X04
SJ1: A0; SJ
SJ2: A1; SJ
SJ3: A2; SJ

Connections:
GND: IC1.4, IC1.7, JP1.2
unnamed: IC1.1, SJ1.2
unnamed: IC1.2, SJ2.2
unnamed: IC1.3, SJ3.2
SCL: IC1.6, JP1.4
SDA: IC1.5, JP1.3
VCC: IC1.8, JP1.1, SJ1.1, SJ2.1, SJ3.1

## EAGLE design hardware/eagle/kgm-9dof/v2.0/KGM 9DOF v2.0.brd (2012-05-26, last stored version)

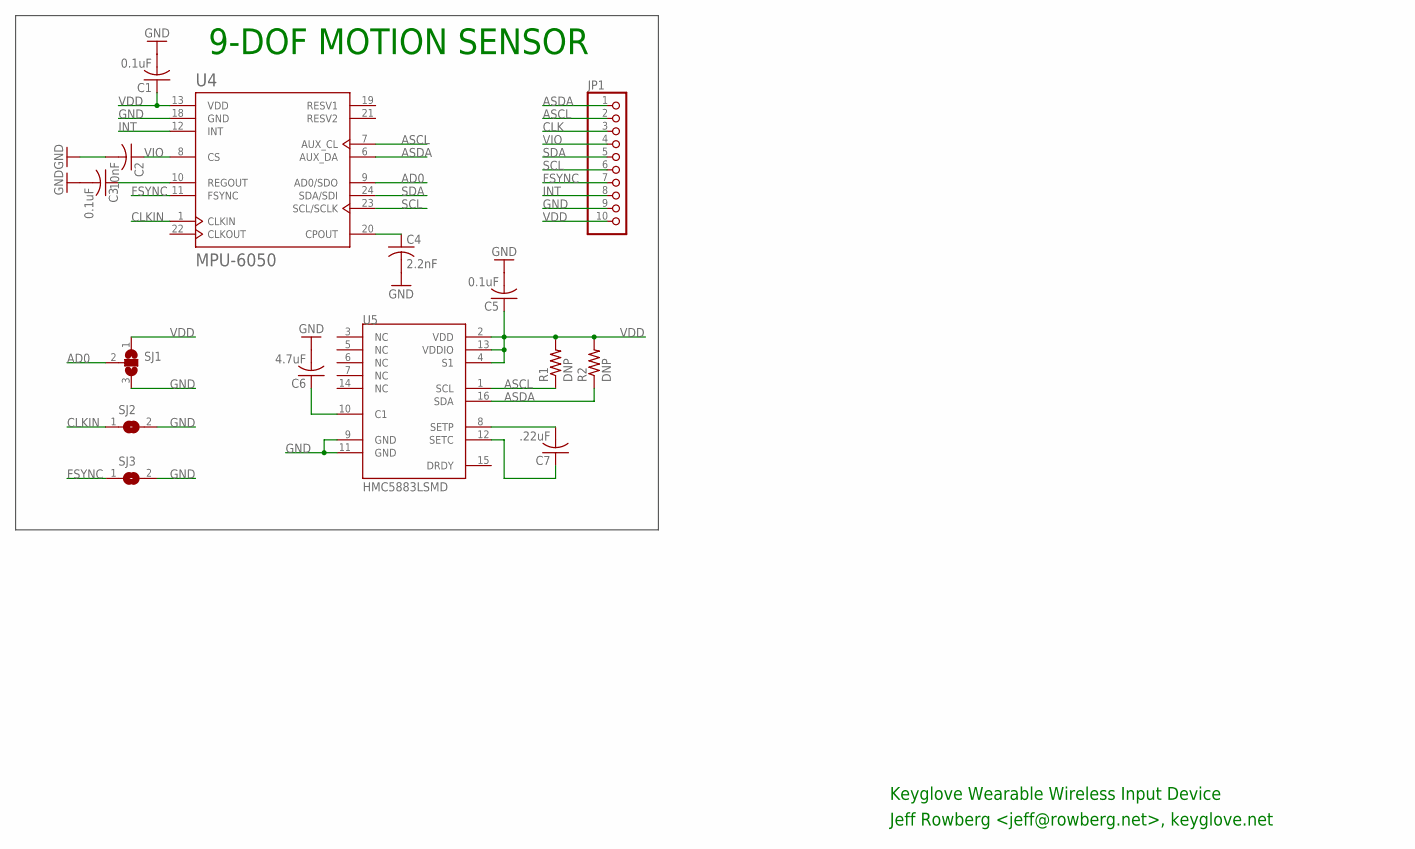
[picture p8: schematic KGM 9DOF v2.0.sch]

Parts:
C1, C3, C5: 0.1uF; C0603
C2: 10nF; C0603
C4: 2.2nF; C0603
C6: 4.7uF; C0603
C7: .22uF; C0603
JP1: PINHD-1X10; 1X10
R1, R2: DNP; R0603
SJ1: SJ2W; SJ_2
SJ2, SJ3: SJ
U4: MPU-6050; QFN24MPU
U5: HMC5883LSMD; 16LPCC

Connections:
AD0: SJ1.2, U4.9 (AD0/SDO)
ASCL: JP1.2, R1.1, U4.7 (AUX_CL), U5.1 (SCL)
ASDA: JP1.1, R2.1, U4.6 (AUX_DA), U5.16 (SDA)
CLK: JP1.3
CLKIN: SJ2.1, U4.1 (CLKIN)
FSYNC: JP1.7, SJ3.1, U4.11 (FSYNC)
GND: C1.2, C2.2, C3.2, C4.2, C5.2, C6.2, JP1.9, SJ1.3, SJ2.2, SJ3.2, U4.18 (GND), U5.9 (GND), U5.11 (GND)
INT: JP1.8, U4.12 (INT)
unnamed: C6.1, U5.10 (C1)
unnamed: C7.2, U5.8 (SETP)
unnamed: C7.1, U5.12 (SETC)
unnamed: C4.1, U4.20 (CPOUT)
unnamed: C3.1, U4.10 (REGOUT)
SCL: JP1.6, U4.23 (SCL/SCLK)
SDA: JP1.5, U4.24 (SDA/SDI)
VDD: C1.1, C5.1, JP1.10, R1.2, R2.2, SJ1.1, U4.13 (VDD), U5.2 (VDD), U5.4 (S1), U5.13 (VDDIO)
VIO: C2.1, JP1.4, U4.8 (CS)

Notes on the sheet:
9-DOF MOTION SENSOR
Keyglove Wearable Wireless Input Device
Jeff Rowberg <jeff@rowberg.net>, keyglove.net

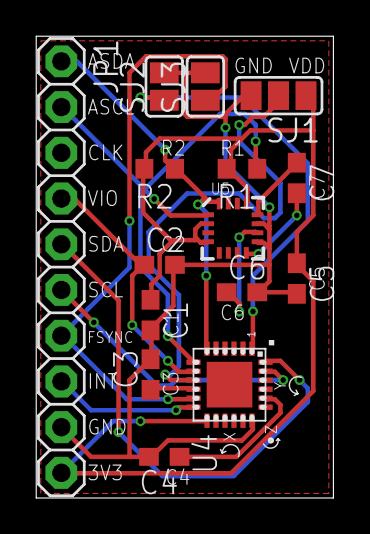
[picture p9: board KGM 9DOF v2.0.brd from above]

Board: 2 copper layers, 16.5 x 25.7 mm, 15 parts (0 on the bottom side), 16 nets.

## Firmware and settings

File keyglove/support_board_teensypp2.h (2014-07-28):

// Keyglove controller source code - Host MCU definitions specific to Teensy++ v2.0
// 7/4/2014 by Jeff Rowberg <jeff@rowberg.net>

/* ============================================
Controller code is placed under the MIT license
Copyright (c) 2014 Jeff Rowberg

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
THE SOFTWARE IS PROVIDED "AS IS", WITHOUT WARRANTY OF ANY KIND, EXPRESS OR
IMPLIED, INCLUDING BUT NOT LIMITED TO THE WARRANTIES OF MERCHANTABILITY,
FITNESS FOR A PARTICULAR PURPOSE AND NONINFRINGEMENT. IN NO EVENT SHALL THE
AUTHORS OR COPYRIGHT HOLDERS BE LIABLE FOR ANY CLAIM, DAMAGES OR OTHER
LIABILITY, WHETHER IN AN ACTION OF CONTRACT, TORT OR OTHERWISE, ARISING FROM,
OUT OF OR IN CONNECTION WITH THE SOFTWARE OR THE USE OR OTHER DEALINGS IN
THE SOFTWARE.
===============================================
*/

/**
 * @file support_board_teensypp2.h
 * @brief Host MCU definitions specific to Teensy++ v2.0
 * @author Jeff Rowberg
 * @date 2014-07-04
 *
 * This file defines all of the hardware-specific parts of the firmware that are
 * unique to the Teensy++ v2.0 platform. Any other hardware-specific code should
 * be added here and abstracted in such a way that other files can use those new
 * features without knowing what is actually happening behind the scenes (here).
 *
 * Normally it is not necessary to edit this file.
 *

Teensy++ 2.0 Pin arrangement:

                     __|||||__
                GND |   USB   | VCC
        3        27 |         | 26        Y
              SCL 0 |         | 25        Z
              SDA 1 |         | 24        a*
              RXD 2 |         | 23        8
              TXD 3 |         | 22        9
        2         4 |  37.36  | 21        0
        1         5 |         | 20        A
              LED 6 |         | 19 INT7
        7         7 |         | 18 INT6
        X         8 |         | GND
        W         9 |         | AREF
        V        10 |         | 38        B
        L    5   11 | 32 . 28 | 39  R     C
        K    G   12 | 33 . 29 | 40  Q     M
        J    H   13 | 34 . 30 | 41  P     N
        6    I   14 | 35 . 31 | 42  F     O
        U        15 |         | 43        4
        T        16 |         | 44        D
        S        17 |_________| 45        E

                  36=INT4, 37=INT5

This is a grand total of 46 usable I/O pins.

- We use SCL (0) and SDA (1) for I2C communication, leaving 44 usable pins.
- We use RXD (2) and TXD (2) for Bluetooth UART communication, leaving 42 usable pins.
- We use INT4 (36) and INT5 (37) for accel and gyro interrupts, leaving 40 usable pins.
- We use INT7 (19) for Bluetooth Link interrupts, leaving 39 usable pins.
- We use INT6 (18) for DTR control, leaving 38 usable pins.
- We use LED for BLINK feedback, leaving 37 usable pins.
- ...and we have a total of 37 sensors. Yay!

Pin Change interrupts (not currently used, could help with sleep modes):

- Y, 26, PB6
- Z, 25, PB5
- a*, 24, PB4
- 8, 23, PB3
- 9, 22, PB2
- 0, 21, PB1
- 1, 5, PD5
- 2, 4, PD4
- 3, 27, PB7

For the sake of the Keyglove Kit board, the sensor pin connections should be arranged
in a clockwise manner as Thumb, Index, Middle, Ring, Little, with each individual
finger's sensors in increasing alphabetical order: (Y,Z,a*,8,9,0), (A,B,C,M,N,O,4),
and so on. Start with pin 26 (B6)

 */

#ifndef _SUPPORT_BOARD_TEENSYPP2_H_
#define _SUPPORT_BOARD_TEENSYPP2_H_

// ======================== BEGIN PIN DEFINITIONS ========================

#define KEYGLOVE_KIT_BUG_PORTA_REVERSED     ///< Software fix for internal Port A pin position bug in Eagle package

#define USBSerial Serial                    ///< USB serial interface name
#define BT2Serial Serial1                   ///< Bluetooth module UART interface name

#define KG_HOSTIF_USB_SERIAL_BAUD 115200    ///< USB serial interface baud rate
#define KG_HOSTIF_BT2_SERIAL_BAUD 125000    ///< Bluetooth module UART interface baud rate

#define KG_INTERRUPT_PIN_ACCEL  36  ///< PE4 (internal/tiny, right)
#define KG_INTERRUPT_NUM_ACCEL  4   ///< Teensy++ interrupt #4

#define KG_INTERRUPT_PIN_GYRO   37  ///< PE5 (internal/tiny, left)
#define KG_INTERRUPT_NUM_GYRO   5   ///< Teensy++ interrupt #5

// FUSION and ACCEL are never both used at the same time
#define KG_INTERRUPT_PIN_FUSION 36  ///< PE4 (internal/tiny, right)
#define KG_INTERRUPT_NUM_FUSION 4   ///< Teensy++ interrupt #4

#define KG_PIN_BLINK            6   ///< PD6

#define KG_PIN_BT_RTS           19  ///< PE7
#define KG_INTERRUPT_NUM_BT_RTS 7   ///< Teensy++ interrupt #7
#define KG_PIN_BT_CTS           18  ///< PE6

// ITEMS BELOW THIS CANNOT BE USED SIMULTANEOUSLY WITH ALL ABOVE FEATURES

// direct I/O feedback pins (kills 3 thumb sensors and Bluetooth flow control)
#define KG_PIN_PIEZO        19  ///< PE7
#define KG_PIN_VIBRATE      18  ///< PE6
#define KG_PIN_RGB_RED      21  ///< PB1
#define KG_PIN_RGB_GREEN    22  ///< PB2
#define KG_PIN_RGB_BLUE     24  ///< PB4
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

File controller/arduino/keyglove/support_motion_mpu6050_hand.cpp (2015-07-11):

// Keyglove controller source code - Motion support implementations for hand-mounted MPU-6050 sensor
// 2015-07-03 by Jeff Rowberg <jeff@rowberg.net>

/* ============================================
Controller code is placed under the MIT license
Copyright (c) 2015 Jeff Rowberg

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
THE SOFTWARE IS PROVIDED "AS IS", WITHOUT WARRANTY OF ANY KIND, EXPRESS OR
IMPLIED, INCLUDING BUT NOT LIMITED TO THE WARRANTIES OF MERCHANTABILITY,
FITNESS FOR A PARTICULAR PURPOSE AND NONINFRINGEMENT. IN NO EVENT SHALL THE
AUTHORS OR COPYRIGHT HOLDERS BE LIABLE FOR ANY CLAIM, DAMAGES OR OTHER
LIABILITY, WHETHER IN AN ACTION OF CONTRACT, TORT OR OTHERWISE, ARISING FROM,
OUT OF OR IN CONNECTION WITH THE SOFTWARE OR THE USE OR OTHER DEALINGS IN
THE SOFTWARE.
===============================================
*/

/**
 * @file support_motion_mpu6050_hand.cpp
 * @brief Motion support implementations for hand-mounted MPU-6050 sensor
 * @author Jeff Rowberg
 * @date 2015-07-03
 *
 * This file provides a communications layer and capture interface for using the
 * InvenSense MPU-6050 motions sensor, mounted on the back of the hand. Only the
 * raw sensor data is currently used from this chip; the DMP is not used for on-
 * module motion fusion.
 *
 * Normally it is not necessary to edit this file.
 */

#include "keyglove.h"
#include "support_board.h"
#include "support_protocol.h"
#include "support_motion.h"
#include "support_motion_mpu6050_hand.h"

MPU6050 mpuHand = MPU6050(0x68);        ///< MPU-6050 motion sensor I2Cdevlib object
bool mpuHandInterrupt;                  ///< Interrupt flag for motion data availability

VectorInt16 aaRaw;                      ///< Raw linear acceleration
VectorInt16 aa;                         ///< Filtered linear acceleration
VectorInt16 aa0;                        ///< Last-iteration filtered linear acceleration
VectorInt16 gvRaw;                      ///< Raw rotational velocity
VectorInt16 gv;                         ///< Filtered rotational velocity
VectorInt16 gv0;                        ///< Last-iteration filtered rotational velocity

/**
 * @brief Interrupt handler for INT pin from MPU-6050
 * @see mpuHandInterrupt
 */
void motion_mpu6050_hand_interrupt() {
    mpuHandInterrupt = true;
}

/**
 * @brief Sets the MPU-6050 sensor mode
 * @param[in] mode Sensor mode (0=disabled, 1=enabled)
 */
void motion_set_mpu6050_hand_mode(uint8_t mode) {
    if (mode) {
        aa.x = aa.y = aa.z = 0;
        gv.x = gv.y = gv.z = 0;
        mpuHandInterrupt = true;
        attachInterrupt(KG_INTERRUPT_NUM_MPU6050_HAND, motion_mpu6050_hand_interrupt, FALLING);
        //mpuHand.setSleepEnabled(false);
        //I2Cdev::writeByte(0x68, MPU6050_RA_PWR_MGMT_1, 0x01);
    } else {
        //mpuHand.setSleepEnabled(true);
        //I2Cdev::writeByte(0x68, MPU6050_RA_PWR_MGMT_1, 0x41);
        detachInterrupt(KG_INTERRUPT_NUM_MPU6050_HAND);
    }
}

/**
 * @brief Initialize MPU-6050 communications and interrupt handler
 *
 * This function sets the MPU-6050 to 100Hz output, 2000 deg/sec resolution for
 * the gyroscope, and enables a latching active-low interrupt on DRDY (raw data
 * ready), MOT (motion detected), and ZMOT (zero motion detected).
 */
void setup_motion_mpu6050_hand() {
    // set INT4 pin (Arduino Pin 36) to INPUT/HIGH so MPU can drive interrupt pin as active-low
    pinMode(KG_INTERRUPT_PIN_MPU6050_HAND, INPUT);
    digitalWrite(KG_INTERRUPT_PIN_MPU6050_HAND, HIGH);

    // setup MPU-6050
    mpuHandInterrupt = false;

    /*
    // initialization with friendly function names
    mpuHand.initialize();
    delay(30);
    mpuHand.setFullScaleGyroRange(MPU6050_GYRO_FS_2000);
    mpuHand.setDLPFMode(MPU6050_DLPF_BW_42);        // 42 Hz DLPF, 1kHz internal sampling
    mpuHand.setRate(9);                             // 1kHz/(9+1) = 100Hz
    mpuHand.setMotionDetectionThreshold(20);
    mpuHand.setMotionDetectionDuration(50);         // 1*50 = 50ms
    mpuHand.setZeroMotionDetectionThreshold(20);
    mpuHand.setZeroMotionDetectionDuration(45);     // 64*45 = ~3 sec
    mpuHand.setInterruptMode(1);                    // active low
    mpuHand.setInterruptDrive(1);                   // open drain
    mpuHand.setInterruptLatch(0);                   // latch until read
    mpuHand.setInterruptLatchClear(1);              // clear on any read
    mpuHand.setIntEnabled(0x41);    // trigger interrupt on data ready, motion, zero-motion
    */

    // initialization with manual register writes (faster than above, fewer transactions)
    // NOTE: InvenSense docs state Mot/ZMot interrupts no longer supported (?!)
    //I2Cdev::writeByte(0x68, MPU6050_RA_MOT_THR, 0x14);
    //I2Cdev::writeByte(0x68, MPU6050_RA_MOT_DUR, 0x32);
    //I2Cdev::writeByte(0x68, MPU6050_RA_ZRMOT_THR, 0x14);
    //I2Cdev::writeByte(0x68, MPU6050_RA_ZRMOT_DUR, 0x2D);
    I2Cdev::writeByte(0x68, MPU6050_RA_INT_PIN_CFG, 0xD0);
    //I2Cdev::writeByte(0x68, MPU6050_RA_INT_ENABLE, 0x61);
    I2Cdev::writeByte(0x68, MPU6050_RA_INT_ENABLE, 0x01);
    I2Cdev::writeByte(0x68, MPU6050_RA_ACCEL_CONFIG, 0x00);
    I2Cdev::writeByte(0x68, MPU6050_RA_GYRO_CONFIG, 0x18);
    I2Cdev::writeByte(0x68, MPU6050_RA_CONFIG, 0x03);
    I2Cdev::writeByte(0x68, MPU6050_RA_SMPLRT_DIV, 0x09);
    I2Cdev::writeByte(0x68, MPU6050_RA_PWR_MGMT_1, 0x01);

    // test motion sensor
    //motion_set_mpu6050_hand_mode(1); // enable motion detection
}
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

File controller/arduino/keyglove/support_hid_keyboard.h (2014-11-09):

// Keyglove controller source code - HID keyboard helper function declarations
// 2014-11-07 by Jeff Rowberg <jeff@rowberg.net>

/* ============================================
Controller code is placed under the MIT license
Copyright (c) 2014 Jeff Rowberg

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
THE SOFTWARE IS PROVIDED "AS IS", WITHOUT WARRANTY OF ANY KIND, EXPRESS OR
IMPLIED, INCLUDING BUT NOT LIMITED TO THE WARRANTIES OF MERCHANTABILITY,
FITNESS FOR A PARTICULAR PURPOSE AND NONINFRINGEMENT. IN NO EVENT SHALL THE
AUTHORS OR COPYRIGHT HOLDERS BE LIABLE FOR ANY CLAIM, DAMAGES OR OTHER
LIABILITY, WHETHER IN AN ACTION OF CONTRACT, TORT OR OTHERWISE, ARISING FROM,
OUT OF OR IN CONNECTION WITH THE SOFTWARE OR THE USE OR OTHER DEALINGS IN
THE SOFTWARE.
===============================================
*/

/**
 * @file support_hid_keyboard.h
 * @brief HID keyboard helper function declarations
 * @author Jeff Rowberg
 * @date 2014-11-07
 */

#ifndef _SUPPORT_HID_KEYBOARD_H_
#define _SUPPORT_HID_KEYBOARD_H_

#ifndef MODIFIERKEY_ALT
    // these are defined by the Teensy libs, if included
    #define MODIFIERKEY_CTRL        0x04
    #define MODIFIERKEY_SHIFT       0x02
    #define MODIFIERKEY_ALT         0x01
    #define MODIFIERKEY_GUI         0x08
    
    #define KEY_A           4
    #define KEY_B           5
    #define KEY_C           6
    #define KEY_D           7
    #define KEY_E           8
    #define KEY_F           9
    #define KEY_G           10
    #define KEY_H           11
    #define KEY_I           12
    #define KEY_J           13
    #define KEY_K           14
    #define KEY_L           15
    #define KEY_M           16
    #define KEY_N           17
    #define KEY_O           18
    #define KEY_P           19
    #define KEY_Q           20
    #define KEY_R           21
    #define KEY_S           22
    #define KEY_T           23
    #define KEY_U           24
    #define KEY_V           25
    #define KEY_W           26
    #define KEY_X           27
    #define KEY_Y           28
    #define KEY_Z           29
    #define KEY_1           30
    #define KEY_2           31
    #define KEY_3           32
    #define KEY_4           33
    #define KEY_5           34
    #define KEY_6           35
    #define KEY_7           36
    #define KEY_8           37
    #define KEY_9           38
    #define KEY_0           39
    #define KEY_ENTER       40
    #define KEY_ESC         41
    #define KEY_BACKSPACE   42
    #define KEY_TAB         43
    #define KEY_SPACE       44
    #define KEY_MINUS       45
    #define KEY_EQUAL       46
    #define KEY_LEFT_BRACE  47
    #define KEY_RIGHT_BRACE 48
    #define KEY_BACKSLASH   49
    #define KEY_NON_US_NUM  50
    #define KEY_SEMICOLON   51
    #define KEY_QUOTE       52
    #define KEY_TILDE       53
    #define KEY_COMMA       54
    #define KEY_PERIOD      55
    #define KEY_SLASH       56
    #define KEY_CAPS_LOCK   57
    #define KEY_F1          58
    #define KEY_F2          59
    #define KEY_F3          60
    #define KEY_F4          61
    #define KEY_F5          62
    #define KEY_F6          63
    #define KEY_F7          64
    #define KEY_F8          65
    #define KEY_F9          66
    #define KEY_F10         67
    #define KEY_F11         68
    #define KEY_F12         69
    #define KEY_PRINTSCREEN 70
    #define KEY_SCROLL_LOCK 71
    #define KEY_PAUSE       72
    #define KEY_INSERT      73
    #define KEY_HOME        74
    #define KEY_PAGE_UP     75
    #define KEY_DELETE      76
    #define KEY_END         77
    #define KEY_PAGE_DOWN   78
    #define KEY_RIGHT       79
    #define KEY_LEFT        80
    #define KEY_DOWN        81
    #define KEY_UP          82
    #define KEY_NUM_LOCK    83
    #define KEYPAD_SLASH    84
    #define KEYPAD_ASTERIX  85
    #define KEYPAD_MINUS    86
    #define KEYPAD_PLUS     87
    #define KEYPAD_ENTER    88
    #define KEYPAD_1        89
    #define KEYPAD_2        90
    #define KEYPAD_3        91
    #define KEYPAD_4        92
    #define KEYPAD_5        93
    #define KEYPAD_6        94
    #define KEYPAD_7        95
    #define KEYPAD_8        96
    #define KEYPAD_9        97
    #define KEYPAD_0        98
    #define KEYPAD_PERIOD   99
#endif /* !MODIFYERKEY_ALT */
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

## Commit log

2010-10-08 Updated main loop with correct test code for PS/2 keyboard library. It outputs a 'k' keypress code roughly once per second--still obviously in the testing stage. The keyboard library works though! I 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
2010-10-13 Updated sensor definitions with new 34-sensor arrangement. Not every possible combination is done, but more than enough for a good touchset. I will probably leave the rest undone until I get my proto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
2010-10-17 New code that is slightly faster, shows correct base pin combination status array for debugging, and has correct pin array references. Working great so far!
2010-10-26 Updated code to include revised PS/2 keyboard and mouse libraries. Main controller code is currently in "mouse test" mode, so keep that in mind if you are downloading it. All of my own code has licen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
2010-10-27 Updated code to include simultaneous keyboard/mouse PS2 devices (technically these are unique, NOT all in one cable!). I can hardly wait for USB on the Teensy.
2010-11-01 Updates to integrate with current version of Processing sketch code
2010-11-14 Updated to show sensor touches more accurately.
2010-11-19 Updated order of currently entered touch combinations to reflect likely touches vs. unlikely (avoids mistakes due to unintended double touches)
2011-01-23 Updated code structure with comments. Added linear and angular velocity calculations. Added velocity-sensitive mouse movement (e.g. cursor acceleration). Added Teensy++ controller board support. Vari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
2011-01-23 Updated to support changed accelerometer serial debug code (includes linear and angular velocity values).
2011-04-24 Major updates to motion sensing code, touchset control, and Bluetooth support. Still not feature-complete or bug-free, but much farther along. Linear/angular velocity calculations not accurate yet, a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
2011-05-30 Fix case of include filename
2011-05-30 Add missing pins for Arduino board
2011-05-30 Add missing key definitions for Arduino, Teensy's hardware library already defines these.
2011-05-30 Add rough code to use a Logitech RX400 board and reciever to get keyboard and mouse events back to the computer
2011-05-30 define the Uart using already defined variables on Arduino
2011-05-30 Fix mouse up for middle and right buttons
2011-05-30 Commit the touchset that I'm using. Has four modes: default (a-z), number, symbol, function. Define all keys on a 101 keyboard except: cursor keys, home, end, pgup, pgdown, capslock Modifier keys (ct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
2011-05-30 Change the precedence on a couple of combinations that I accidently hit a second contact at the same time
2011-06-11 Updates to tilt calculation code, added accel/gyro rotation settings, disabled vibration motor temporarily. New files include 3D axis template for Google SketchUp and PHP smart touchset generation sc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
    [3d-axis-template.skp]
2011-07-01 Fixed USB descriptor in LUFA version so that all devices enumerate correctly
2011-07-09 Integrated Wiring with LUFA, modified Keyglove LUFA code to incorporate existing Arduino code and compile with limited functionality so far.
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2011-07-10 Filled in USBVirtualSerial functions for compatibility with Arduino-style Serial object
2011-09-26 Update new files, convert to Arduino 1.0 compatibility
2011-09-26 Update for Arduino 1.0 compatibility, new code structure
2011-09-26 Added schematics and PCBs for the current batch of independent Keyglove modules
    [KGM 6DOF v1.0.brd, KGM 6DOF v1.0.sch, KGM 9DOF v1.0.brd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]
2011-09-29 Add 6DOF and 9DOF schematic/PCB image files for quick reference
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2011-10-01 Update LUFA to 111009, I2Cdev class to include new NBWire implementation to remove Arduino Wire dependency
2011-10-04 Add missing LUFA framework files to repository
2011-10-04 Implement intelligent use of ARDUINO constant from environment
2011-10-26 Major updates for interrupt-driven behavior, motion processing (which is still a bit buggy), and serial communication protocol
    [keyglove.ino]
2011-10-31 Add board support for preliminary testing with Arduino Mega again
2011-10-31 Move raw IMU motion functionality to its own header file
2011-10-31 Update motion control, fix interrupt problem, set I2C implemention back to Arduino Wire for the time being, add more serial control commands.
    [keyglove.ino]
2011-11-01 Fix scaling of IMU filter gyro update arguments
2011-11-23 Very slight update to MPU-6050 QFN-24 footprint (cover center pad with solder mask)
    [KGM 6DOF v1.0.brd, KGM 6DOF v1.0.sch, KGM 9DOF v1.0.brd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]
2012-02-15 Moved default registers to PROGMEM, fixed per-byte configuration application method and I2C control to fit in available RAM
2012-03-08 Added simple I2C slave test program for ATTiny44 MCU
2012-03-08 Major improvements to main RGB driver code, fully functional except I2C
2012-03-09 Greatly simplified entire codebase, added I2C START callback, tested and completely working
2012-03-10 Add complied .hex files for I2C feedback module programs
2012-05-26 Add KG Kit v0.1-v0.4, KGM 9DOF v2.0, EEPROM v1.1, Feedback v2.0 and v2.1
    [KGM 9DOF v2.0.brd, KGM 9DOF v2.0.sch, KGM EEPROM v1.1.brd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]
2012-05-26 MPU-6050 raw support, new structural changes, serial protocol basics, I2C feedback support
2012-05-26 Add feedback connection setup files (direct vs. I2C) and some new motion sensor/IMU code
2012-07-03 New files, MPU code, 400kHz I2C, serial protocol, and scaled gyro measurements for better mouse control
2013-09-02 Adding Keyglove-specific Eagle libraries in their current state
2013-09-08 Committing all latest changes (including early Arduino Due support) before restructuring code
2013-11-17 Massive code changes to provide baseline working Teensy++ hardware configuration
2013-11-24 Fix MPU-6050 hand motion sensor interrupt functionality
    [keyglove.ino]
2014-07-28 Massive update to integrate new KGAPI structure, complete Doxygen documentation, and working fundamental firmware implementation on Teensy++ 2.0 platform
2014-08-02 Fix kg_cmd_bluetooth_set_mode() to fail if interface is not ready, not just if it is not ready AND the new mode is different
    [support_bluetooth2_iwrap.h]
2014-11-02 Add support for 19-pin configuration with Teensy++ 2.0
2014-11-02 Add kg_evt_system_battery_status event and support for scheduled soft timers
2014-11-02 Add battery and soft timer API command functions
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2014-11-02 Clean up MPU6050 hand motion sensor code for efficiency and proper API integration
2014-11-02 Fix Bluetooth interface detection for incoming serial/RawHID data
    [support_bluetooth2_iwrap.h]
2014-11-09 Restructure Arduino project into standard .cpp/.h form, update Doxygen comments
2014-11-11 Fix whitespace because I am ridiculously picky
    [support_bluetooth2_iwrap.h]
2014-11-11 Fix assignment operator to be equality
    [support_bluetooth2_iwrap.cpp]
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2014-11-15 Close links when removing pairings, fix infinite loop bug in bluetooth_get_connections
    [support_bluetooth2_iwrap.cpp]
2014-11-15 Fix page mode change in autocall mode
    [support_bluetooth2_iwrap.cpp]
2014-11-30 Fix Bluetooth link closure event handler to remove mapped connection
    [support_bluetooth2_iwrap.cpp]
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2014-12-06 Remove old and irrelevant material to tidy up
    [3d-axis-template.skp, KGM 6DOF v1.0.brd, KGM 6DOF v1.0.sch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]
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2014-12-07 Add README link to main project page, embedded prototype image
2014-12-07 Update autogen Arduino controller support files with new date and license format
2014-12-08 Add capability API request declarations to Arduino and Python code
2014-12-15 Basic capability reporting event structure for currently existing categories
2015-03-14 Fix bitwise logic error in battery status value assignment
    [support_board_teensypp2_t19.cpp]
2015-03-14 Change battery measurements to use MAX17048 instead of ADC input
2015-04-01 Fix typo in vibrate code referring to piezo hardware
    [support_feedback_vibrate.cpp]
2015-04-01 Add I2Cdev include to main include for battery support
2015-04-01 Add conditional macro around Bluetooth code in sample application
2015-04-01 Include specific feedback header files to avoid compile errors with certain config selections
    [support_feedback_rgb.cpp]
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

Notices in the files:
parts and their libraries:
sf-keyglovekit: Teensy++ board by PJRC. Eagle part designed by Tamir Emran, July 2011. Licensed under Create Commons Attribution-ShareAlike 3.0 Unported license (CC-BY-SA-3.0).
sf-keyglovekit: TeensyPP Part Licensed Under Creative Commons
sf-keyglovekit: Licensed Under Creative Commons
